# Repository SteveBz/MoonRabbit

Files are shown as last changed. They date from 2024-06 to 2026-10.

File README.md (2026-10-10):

# Moon Rabbit CO<sub>2</sub> Sensor

> **You are here:** project overview.
> Jump to: [BOM](BOM.md) · [BUILD](BUILD.md) · [SOFTWARE BUILD](SOFTWARE_BUILD.md) · [CALIBRATION](CALIBRATION.md)
> 
**A Raspberry Pi Zero 2 CO<sub>2</sub> and climate monitoring station.**

Moon Rabbit is a low-cost, open-source environmental sensor built around a Raspberry Pi Zero 2. At its core it measures **CO<sub>2</sub>** (Sensirion SCD30) and **temperature, humidity and pressure** (Bosch BME280). It can be upgraded with more precise temperature/humidity (Sensirion SHT41), air-quality gases VOC and NOx (Sensirion SGP41), sky luminosity (TSL2591), and it is compatible with a range of weather stations — notably the **Davis Vantage Pro** series, **Ambient Weather**, and **Ecowitt**.

It runs as a micro server on your WiFi, giving you 24×7 CO<sub>2</sub> and climate indicators through a browser dashboard.

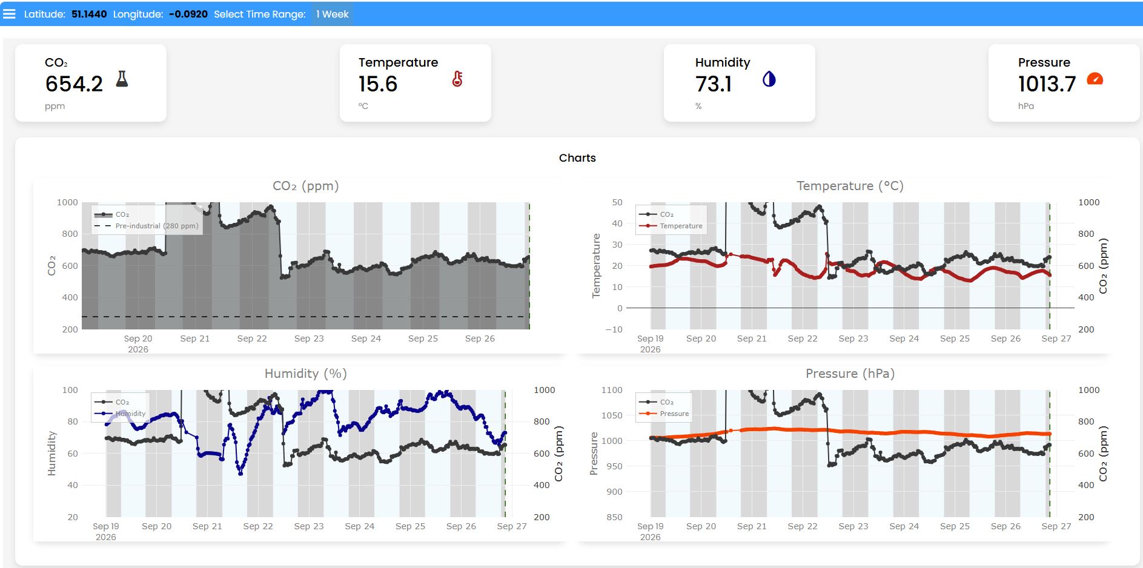
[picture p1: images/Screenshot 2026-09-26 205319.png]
Moon Rabbit sensors
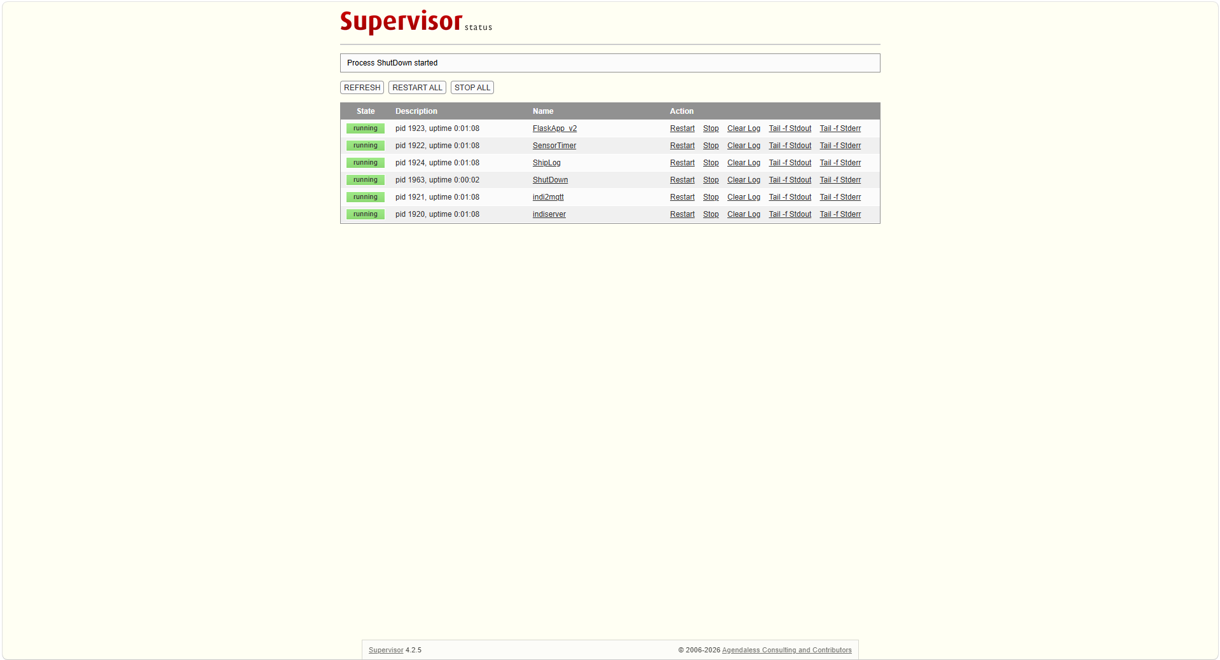
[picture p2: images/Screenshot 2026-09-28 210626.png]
Moon Rabbit control panel
|  |  |
|:---:|:---:|
| Moon Rabbit Sensors | Moon Rabbit Control Panel |

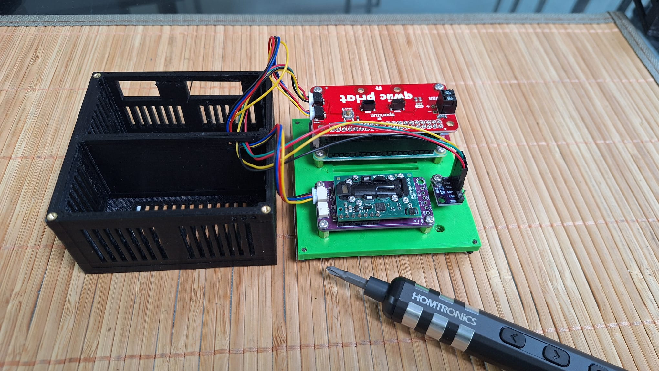
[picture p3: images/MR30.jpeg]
Moon Rabbit case
|  | |
|:---:|:---:|
| 3D-printed case with Raspberry Pi Zero 2, Qwiic pHAT, SCD30 and BME280. | |

---

## Documentation

This project is documented across four files. Start with the one that matches what you want to do.

| Document | Description |
|---|---|
| **[BOM.md](BOM.md)** | Bill of materials — every part, bolt and cable you need |
| **[BUILD.md](BUILD.md)** | Physical build — 3D printing, assembly, wiring |
| **[SOFTWARE_BUILD.md](SOFTWARE_BUILD.md)** | Software installation — OS, Python, Supervisor, MQTT, weather-station bridges |
| **[CALIBRATION.md](CALIBRATION.md)** | Sensor calibration and validation (in progress) |

### Typical build sequence

1. Order the parts listed in **[BOM.md](BOM.md)**.
2. Print the case and assemble the hardware per **[BUILD.md](BUILD.md)**.
3. Flash and configure the Pi per **[SOFTWARE_BUILD.md](SOFTWARE_BUILD.md)**.
4. (Optional) Calibrate the CO<sub>2</sub> sensor per **[CALIBRATION.md](CALIBRATION.md)**.

---

## Hardware design files

The 3D-printed case is provided as two STL files in the repository root:

- [`MoonRabbitCase_v0.4.stl`](MoonRabbitCase_v0.4.stl) — the base
- [`CarbonSensorStand_v0.9.stl`](CarbonSensorStand_v0.9.stl) — the shell / stand

Print settings and assembly guidance are in **[BUILD.md](BUILD.md)**.

---

## Licence

Software: [MIT](LICENSE) — see the `LICENSE` file.
Hardware design files: [CC BY-SA 4.0](https://creativecommons.org/licenses/by-sa/4.0/).

## Acknowledgements

- Bosch, Sensirion, SparkFun and Adafruit for sensors and open-source libraries
- The [`indi2mqtt`](https://github.com/rkaczorek/indi2mqtt) project for the Vantage Pro bridge
- [`ecowitt2mqtt`](https://github.com/bachya/ecowitt2mqtt) for the Ecowitt / Ambient Weather bridge

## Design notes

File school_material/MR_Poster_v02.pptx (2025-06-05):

## Climate change and Moon Rabbit

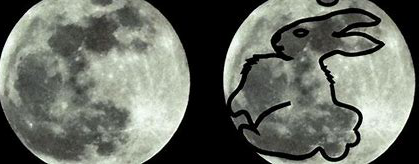
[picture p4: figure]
Image result for moon rabbit

## Moon Rabbit Projects

- Building Moon Rabbit: Construct and deploy a DIY, Moon Rabbit CO₂ monitors to empower students to collect and analyse environmental data
- CO₂ and Learning: Measure classroom CO₂ levels and correlate them with student concentration and test performance over a term.
- Traffic and Air Quality: Compare CO₂ levels in classrooms at varying distances from major roads to assess the impact of traffic emissions.
- CO₂ and the Daily Cycle: Track diurnal CO₂ changes in school grounds to explore links between photosynthesis, cloud cover and air quality.
- Many more...

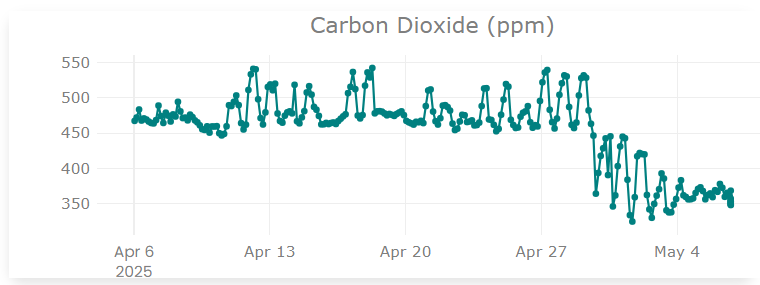
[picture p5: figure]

Skills developed
These projects help students build real-world scientific and technical skills, including 3D printing, coding and electronics (Raspberry Pi), sensor calibration, environmental data collection, data analysis, graphing and critical thinking. They also encourage teamwork, project planning, experimental design, and communication — all while connecting science learning to urgent global challenges like climate change.

## Climate change & Moon Rabbit

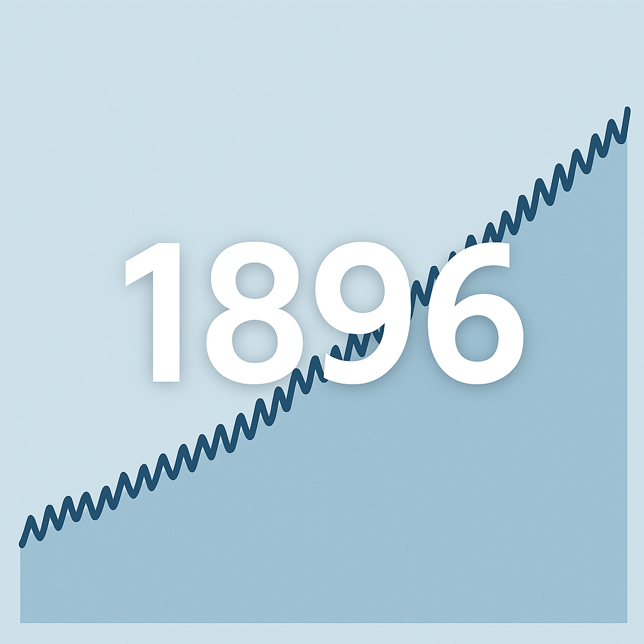
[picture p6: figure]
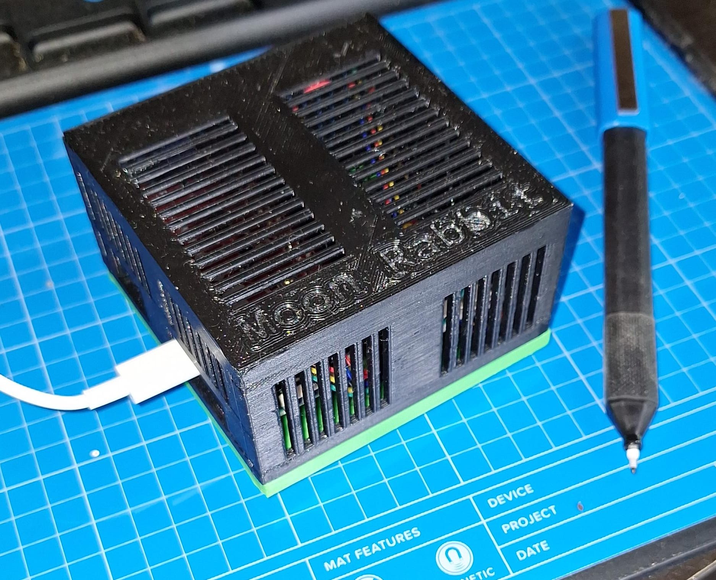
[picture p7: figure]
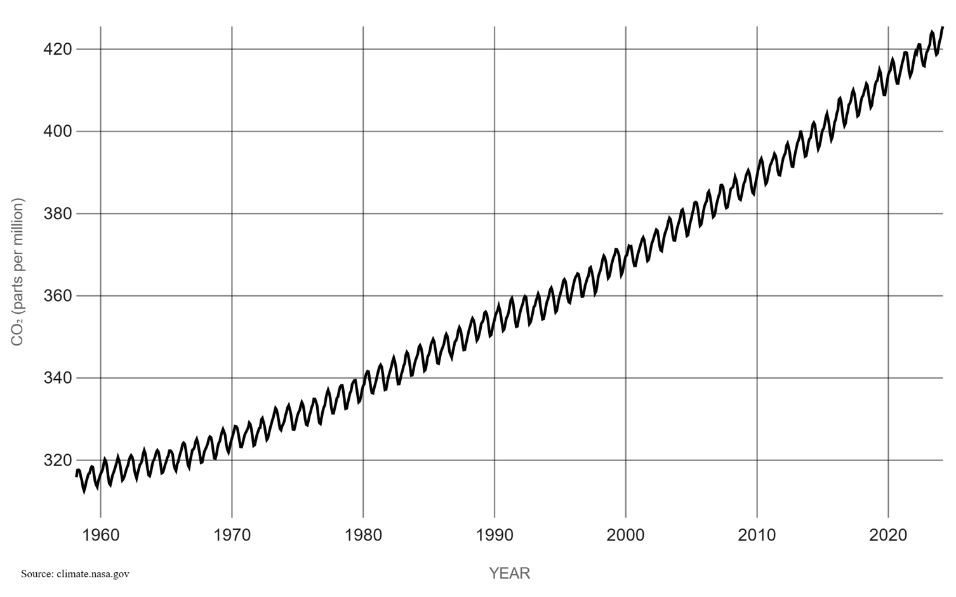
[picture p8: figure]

Kyoto
Protocol

Paris
Accord

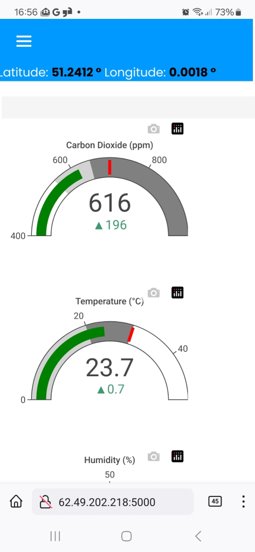
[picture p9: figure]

Build your own CO2 sensor to educate and empower
Self-directed learning for the education & STEM community
Enables students, educators & families to build and deploy their own devices
Together, we are building a global CO2 community to inform, inspire, and help shape a more sustainable future.
Real-time CO2 data on your mobile or PC
Explore globally via an interactive map
Promotes environmental awareness and STEM education

Atmospheric
CO2

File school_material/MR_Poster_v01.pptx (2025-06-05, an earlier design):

## Climate change and Moon Rabbit

Image result for moon rabbit

## Climate change & Moon Rabbit


Kyoto
Protocol

Paris
Accord


Self-built, dynamic real-time CO2 sensor designed to educate and empower communities worldwide.
Captures CO2 readings continuously, publishing data to your mobile device or PC and globally via an interactive map to explore in detail.
Moon Rabbit is a programme of self-build, experimentation and self-directed learning, tailored for the education community.
By enabling students, educators and families to build and deploy their own Moon Rabbit devices, the project fosters environmental awareness and hands-on STEM education.
Together, we are building a community-driven, global CO2 map to inform, inspire, and help shape a more sustainable future.

Atmospheric
CO2

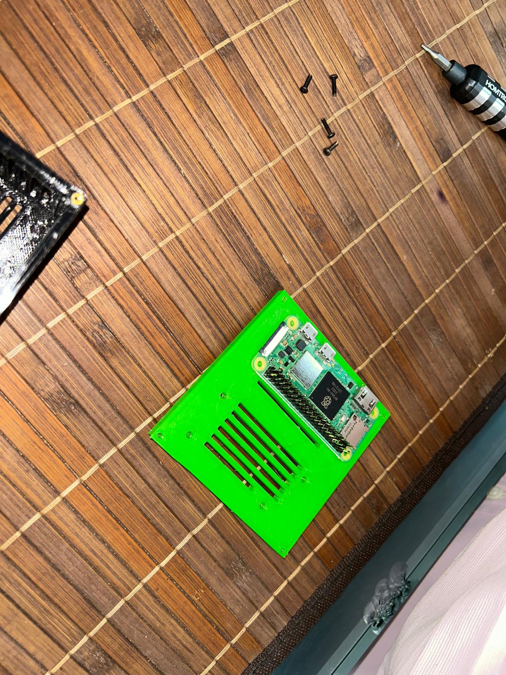
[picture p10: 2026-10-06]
images/MR17.jpeg

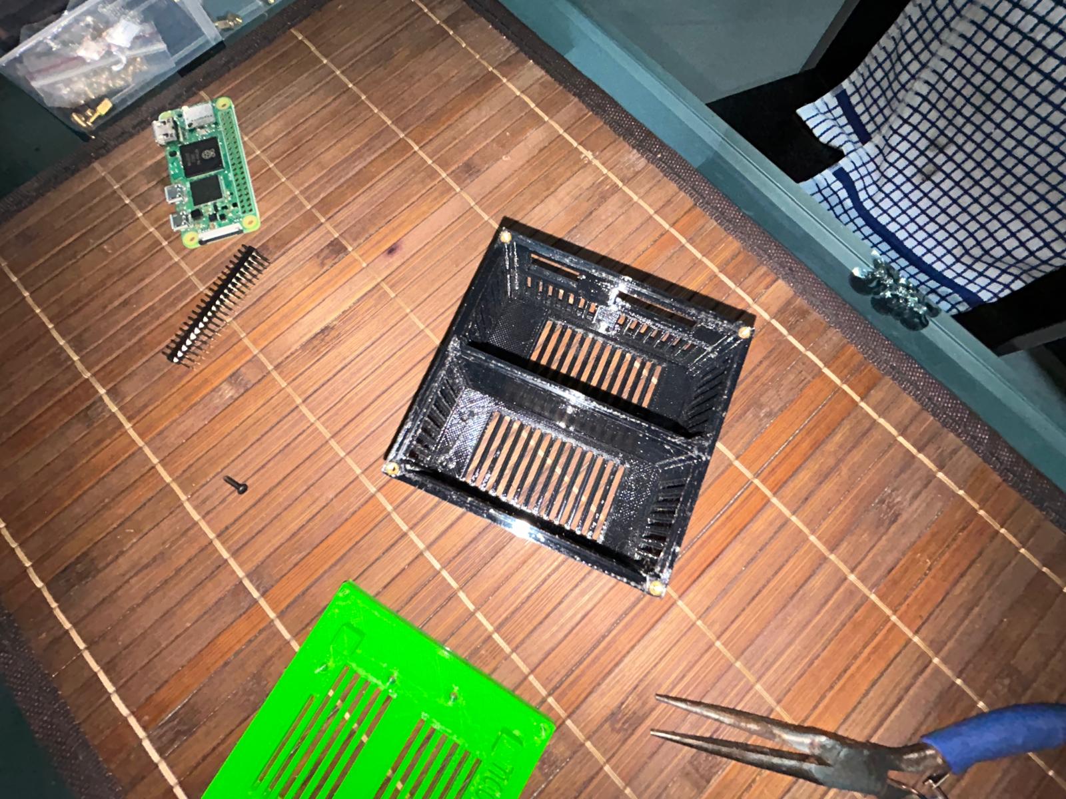
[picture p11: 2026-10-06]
images/MR9.jpeg

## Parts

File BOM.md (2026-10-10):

# Bill of Materials

> **You are here:** bill of materials — the parts list.
> Jump to: [README](README.md) · [BUILD](BUILD.md) · [SOFTWARE BUILD](SOFTWARE_BUILD.md) · [CALIBRATION](CALIBRATION.md)

Everything required to build one Moon Rabbit station. Prices are indicative (GBP, 2026), exclude shipping, and assume a UK/EU supplier. Substitute your preferred source.

## Enclosure

| Item | Qty | Notes | Source |
|---|-----|---|---|
| 3D-printed base | 1 | [`MoonRabbitCase_v0.4.stl`](MoonRabbitCase_v0.4.stl) | Print locally |
| 3D-printed shell | 1 | [`CarbonSensorStand_v0.9.stl`](CarbonSensorStand_v0.9.stl) | Print locally |
| M2 threaded inserts (shell) | 4 | Heat-set, ~4 mm | Generic |
| M3 threaded inserts (base) | 8 | Heat-set | Generic |
| M2 × 8 mm hex-head bolts | 4 | Attach shell to base | Generic |
| M2.5 × 6 mm cross-head bolts | 8 | Mount Pi and Qwiic HAT | Generic |
| M2.5 × 6 mm standoffs | 8 | Between Pi and Qwiic HAT | Generic |
| M2.5 × 11 mm standoffs | 2 | Sensor mounting | Generic |

## Electronics

| Item | Qty | Notes | Source |
|---|-----|---|---|
| Raspberry Pi Zero 2 W **or** WH | 1 | **WH** = pre-soldered GPIO header (recommended) | Pi Hut / Adafruit |
| 40-pin GPIO header | 1 | Only if using the non-WH board | Generic |
| SparkFun Qwiic pHAT for Pi | 1 | I²C breakout + Qwiic socket | SparkFun |
| Bosch BME280 breakout | 1 | Qwiic or pinout version | Adafruit / SparkFun |
| Sensirion SCD30 CO<sub>2</sub> sensor | 1 | NDIR. Qwiic version recommended | Sensirion / SparkFun |
| Qwiic-to-Qwiic cable, 10 cm | 1 | HAT → SCD30 | SparkFun |
| Qwiic-to-4-pin-female cable | 1 | HAT → BME280 (pinout version only) | SparkFun |
| MicroSD card, 32 GB, Class 10 | 1 | Samsung / SanDisk recommended | Generic |
| MicroSD card reader | 1 | For flashing the Pi | Generic |

## Optional upgrades

| Item | Qty | Notes | Source |
|---|-----|---|---|
| SHT41 breakout | 1 | Better humidity precision than BME280 | Adafruit / SparkFun |
| SGP41 breakout | 1 | VOC / NOx gas sensing | Sensirion / Adafruit |
| TSL2591 breakout | 1 | Sky luminosity (lux, IR, full spectrum) | Adafruit |
| Qwiic cable, 5 cm | 2–3 | One per upgrade sensor | SparkFun |
| IP65 enclosure, clear window | 1 | For the outdoor TSL2591 | Generic |
| Outdoor mounting bracket | 1 | For the IP65 enclosure | Generic |
| 4-core cable, ~2 m | 1 | TSL2591 (outdoor) → main case | Generic |
| 4-pole 2.5 mm panel socket | 1 | On the main case | Generic |
| 4-pole 2.5 mm plug | 1 | On the outdoor box | Generic |

## Tools

| Item | Notes |
|---|---|
| Electric screwdriver | e.g. Homtronics 37 in 1 electric screwdriver — speeds assembly |
| Miniware TS101 soldering iron | Heat-set inserts, pin headers |
| Solder, 0.6–0.8 mm lead-free | Fine-pitch work |
| Soldering stand / helping hands | Holds small boards during soldering |
| Silicone soldering mat | Heat-resistant, keeps parts in place |

## Not included

- **Power supply** — the Pi Zero 2 W needs a **5 V, 2.5 A micro-USB** supply (not USB-C).
- **Weather station** — Vantage Pro, Ambient Weather, or Ecowitt, purchased separately. See [SOFTWARE_BUILD.md](SOFTWARE_BUILD.md) for setup.

## Approximate cost

| Tier | Cost (GBP) |
|---|---|
| Core kit | £70–£90 |
| + SHT41 | +£12 |
| + SGP41 | +£20 |
| + TSL2591 outdoor kit | +£25 |
| + Weather station | £150–£500 (model dependent) |

---

*See [BUILD.md](BUILD.md) for assembly, [SOFTWARE_BUILD.md](SOFTWARE_BUILD.md) for the software setup.*

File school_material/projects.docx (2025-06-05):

# CO2 Monitoring Projects for After-School Club

# Summary

This document provides a comprehensive collection of CO2 monitoring projects designed for an after-school club using cheap pre-built 3D sensors that measure CO2, temperature, pressure, and humidity. The projects span various environments and learning objectives, offering engaging hands-on activities for students to understand environmental monitoring and the carbon cycle.

# Project Development Process

1. Brainstorming: We researched and developed 16 diverse project ideas spanning environmental monitoring and experimental approaches
2. Selection: We selected 8 projects based on engagement potential, educational value, and feasibility for after-school implementation
3. Detailed Development: Each selected project was developed with comprehensive procedures, materials lists, and expected outcomes
4. Validation: All projects were validated for relevance, feasibility, and educational value in an after-school setting

# Recommended Projects

Here is a list of project outlines:

### 1. Living Near a Road

- Measure and compare CO₂ levels at different distances from a busy road.
- Investigate the relationship between traffic density and CO₂ concentration.
- Assess potential health or environmental impacts on residents.

### 2. Urban vs. Rural Living (CO₂)

- Compare CO₂ levels in urban and rural school locations.
- Analyse how population density and transport patterns affect air quality.
- Discuss implications for sustainable living and urban planning.

### 3. Gas Central Heating (CO₂)

- Measure indoor CO₂ during heating vs. non-heating periods.
- Compare homes with gas heating to those using alternatives (e.g., electric).
- Examine the role of ventilation and insulation in indoor air quality.

### 4. Living Near an Industrial Area (CO₂)

- Monitor CO₂ near industrial zones vs. residential zones.
- Investigate possible spikes during working hours or specific processes.
- Explore links between industrial activity, emissions, and local environment.

### 5. Year-on-Year Change (CO₂)

- Compare CO₂ data from the same period across multiple years.
- Identify trends and possible causes (e.g., policy changes, weather patterns).
- Use historical data to project future scenarios or improvements.

### 6. Daily Variation and Photosynthesis

- Record CO₂ levels over 24-hour cycles in areas with and without vegetation.
- Identify patterns linked to photosynthesis during daylight hours.
- Discuss the importance of green spaces in regulating CO₂.

### 7. Student Performance or Behaviour vs. CO₂

- Track classroom CO₂ levels and correlate with concentration or test results.
- Observe behavioural patterns at high vs. low CO₂ levels.
- Propose ventilation or scheduling strategies to improve learning conditions.

### 8. Collaborating with Other Schools

- Share CO₂ data with schools in different locations or countries.
- Compare environmental impacts of geography, infrastructure, and lifestyle.
- Develop joint reports or campaigns on improving air quality.

### 9. Classroom Air Quality Investigation

- Monitor CO₂ levels in different classrooms to understand ventilation and occupancy effects.
- 2–4 week time-frame with minimal additional resources required.
- Strong connections to environmental science and building health.

### 10. CO₂ in Crowded vs. Empty Spaces

- Investigate how human occupancy affects CO₂ build-up in enclosed spaces.
- Shorter 1–2 week time-frame ideal for maintaining engagement.
- Immediate relevance to student experience with clear, observable results.

### 11. Plant Photosynthesis and CO₂ Study

- Create controlled environments to measure how plants affect CO₂ levels.
- 2–3 week time-frame with moderate resource needs (plants, containers).
- Excellent hands-on learning about photosynthesis and the carbon cycle.

### 12. Home vs. School Environmental Comparison

- Compare CO₂ and environmental factors between homes and school buildings.
- 2–4 week time-frame requiring permission for home sensor use.
- Strong personal relevance increases student engagement.

### 13. School Microclimate Mapping

- Create maps of CO₂, temperature, pressure, and humidity across the school campus.
- 3–5 week time-frame with excellent environmental diversity.
- Develops spatial mapping and data visualization skills.

### 14. Composting and Decomposition CO₂ Study

- Monitor CO₂ production during decomposition of organic materials.
- 3–5 week time-frame with moderate resource needs.
- Strong connections to biology, carbon cycle, and sustainability.

### 15. Weather and CO₂ Relationship Study

- Investigate correlations between weather conditions and CO₂ levels.
- Consider shortening from proposed 4–6 weeks to fit club schedule.
- Excellent connections to meteorology and climate science.

### 16. Traffic and Air Quality Correlation

- Measure how vehicle traffic affects local CO₂ levels at varying distances.
- Requires careful safety protocols for roadside measurements.
- Strong real-world relevance to environmental science and transportation.

# Implementation Recommendations

1. Getting Started: Begin with projects to build student confidence and skills
2. Project Selection: Choose subsequent projects based on student interest and available resources
3. Adaptability: Modify project scope as needed to fit your specific club schedule and equipment
4. Documentation: Encourage students to maintain detailed records of their observations and measurements
5. Extension: Consider culminating with a school environmental fair to showcase student findings.

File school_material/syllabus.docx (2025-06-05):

# Moon Rabbit Syllabus

First Term

### Term 1 Introduction: Building Moon Rabbit

Term 1 of the after-school STEM course provides students with the foundational knowledge and technical skills required to build a Moon Rabbit CO2 sensor which we will deploy in Terms 2 and 3 (see CO2 Monitoring Projects document).

The Moon Rabbit is a compact, Raspberry Pi–based CO2 monitoring system designed to collect CO2 measurements and associated metrics. During this first term, students will construct and deploy of their own Moon Rabbit units while developing skills in 3D design, electronics assembly, programming and calibration.

#### Focus of Term 1

Term 1 is structured around guided skill-building, preparation, build and calibration of the Moon Rabbit sensor. Students will:

- Gain an overview of the Moon Rabbit project and its objectives
- Learn the basics of 3D modelling using TinkerCAD
- Design/Modify and print custom enclosures for their devices
- Develop practical soldering skills and assemble core electronic components
- Install and configure the Raspberry Pi operating system
- Begin programming in Python, including basic control structures and system navigation
- Calibrate and test their Moon Rabbits

Students will work in pairs throughout the term, encouraging collaboration and peer learning. Team roles will be established early to support division of tasks during the project.

#### Outcomes

By the end of Term 1, students are expected to have:

- Completed and printed their custom Moon Rabbit enclosures
- Installed key components, including Raspberry Pi Zero and sensors
- Installed Raspberry Pi OS and configured the system for operation
- Installed and tested pre-built Python scripts for system control and data handling
- Calibrated and tested the Moon Rabbits

This work ensures that students are well-prepared to move into the applied phases of the course in Terms 2 and 3, where the emphasis shifts to CO2 monitoring in different circumstances and determining the impact of varying levels of CO2 on their environments.

### Week 1: Introduction and Project Overview

Objectives:

- Introduce students to the project goals and timeline
- Familiarise students with Moon Rabbit basics
- Form working pairs and establish team roles.
- Learn basics of 3D design
- Start designing an enclosure

Activities:

1. Welcome and introduction to the project (10 minutes)
2. Overview of Moon Rabbit and its capabilities (30 minutes)
3. Demonstration of a completed Moon Rabbit (20 minutes)
4. Form pairs (10 minutes)
5. Team building activity: Pairs create team names and discuss project goals (15 minutes)
6. Introduction to 3D design principles (20 minutes)
7. Overview of TinkerCAD 3D design software (15 minutes)

Homework: Design a hollow project box on TinkerCAD.

### Week 2: 3D Design Introduction

Objectives:

- Understand design considerations for electronics enclosures
- Complete Moon Rabbit designs.

Activities:

1. Feedback on Project Box designs (15 minutes)
2. Review of design principles and addressing questions (15 minutes)
3. Measuring Moon Rabbit for SD Slot (15 minutes)
4. Pairs begin designing their own SD Slots (30 minutes)
5. Finalising Moon Rabbit designs with proper ventilation and access ports (20 minutes)
6. Peer review of designs in groups (15 minutes)
7. Saving designs and preparing for next session (10 minutes)

Homework: Finalise Moon Rabbit designs.

### Week 3: Finalising 3D Design and Starting Prints

Objectives:

- Prepare files for 3D printing.
- Introduction to Cura slicing software.
- Slice Moon Rabbit case.
- Start printing process.
- Learn soldering safety and techniques
- Practice basic soldering skills

Activities:

1. Introduction to Cura slicing software and print settings (20 minutes)
2. Preparing files for printing and estimating print times (20 minutes)
3. Starting the printing process for some groups (20 minutes)
4. Introduction to soldering safety and equipment (20 minutes)
5. Demonstration of proper soldering techniques (20 minutes)
6. Solder BME280 joints (20 minutes)

Homework: Complete printing.

### Week 4: Soldering RPi 0 headers

Objectives:

- Prepare Raspberry Pi headers for the project.
- Clean up prints

Activities:

1. Inspecting solder joints and troubleshooting common issues (15 minutes)
2. Practice soldering with simple components (header pins to Raspberry Pi Board) (60 minutes)
3. Inspecting solder joints and troubleshooting common issues (15 minutes)
4. Clean-up and proper disposal of soldering materials (5 minutes)
5. Collecting completed 3D prints (10 minutes)
6. Post-processing of 3D Moon Rabbit cases (sanding, spray) (20 minutes)

Homework: Complete clean-up.

### Week 5: Assembly and Integration

Objectives:

- Assemble 3D printed enclosures
- Mount Raspberry Pi and sensors
- Test the integrated system

Activities:

1. Mounting Raspberry Pi in the enclosure (30 minutes)
2. Installing sensors in appropriate locations (30 minutes)
3. Connecting all components in the final configuration (30 minutes)
4. Initial testing of the assembled system (30 minutes)

Homework: Prepare for final testing and think about potential projects.

### Week 6: Operating System Setup and Basic Linux Commands

Objectives:

- Install and configure Raspberry Pi OS
- Learn basic Linux commands
- Understand file system navigation

Activities:

1. Review of first half and address questions (15 minutes)
2. Install Raspberry Pi OS using the Raspberry Pi Imager (30 minutes)
3. First boot and initial configuration (20 minutes)
4. Basic setup: Connecting Pi to monitor, keyboard, mouse, connect to WiFi (40 minutes)
5. Introduction to Terminal and basic Linux commands (cd, ls, mkdir, etc.) (10 minutes)
6. Saving work and proper shutdown procedures (5 minutes)

Homework: Practice Linux commands using an online terminal simulator

### Week 7: Introduction to Python Programming

Objectives:

- Learn Python basics
- Write simple programs on the Raspberry Pi
- Understand variables, loops, and conditionals

Activities:

1. Introduction to Python and why it's used for this project (15 minutes)
2. Setting up Python development environment on Pi (15 minutes)
3. Guided coding: Variables, data types, and simple operations (30 minutes)
4. Pair programming exercise: Creating a simple temperature monitoring program (30 minutes)
5. Introduction to conditional statements and loops (20 minutes)
6. Saving and running Python scripts (10 minutes)
7. Introduction to sensor calibration principles (20 minutes)

Homework: Complete a simple Python challenge related to weather data

### Week 8: Testing, and Troubleshooting

Objectives:

- Ensure all systems are functioning correctly
- Troubleshoot any issues

Activities:

1. Final system checks and troubleshooting (30 minutes)
2. Testing the complete CO2 monitoring system (20 minutes)
3. Each pair presents their project and demonstrates functionality (30 minutes)

Homework:

### Week 9: Calibration with Vacuum Pump and Calibration Gas

Objectives:

- Understand the importance of sensor calibration
- Learn calibration techniques for pressure and CO2 sensors
- Implement calibration in code

Activities:

1. Safety briefing for working with vacuum pumps and calibration gas (15 minutes)
2. Demonstration of calibration setup and equipment (20 minutes)
3. Calibrating pressure sensors using vacuum pump (30 minutes)
4. Calibrating CO2 sensors using calibration gas (30 minutes)
5. Implementing calibration offsets in Python code (5 minutes)

Homework:

### Week 10: Catchup, Final Testing and Presentation

Objectives:

- Complete any unfinished work from previous weeks
- Ensure all systems are functioning correctly
- Discuss future applications
- Present final projects

Activities:

1. Catchup time for groups who need to complete previous steps (30 minutes)
2. Final calibration checks and adjustments (20 minutes)
3. Each pair presents their project and demonstrates functionality (30 minutes)
4. Discussion of potential applications and future enhancements (15 minutes)
5. Project wrap-up and celebration of achievements (5 minutes)

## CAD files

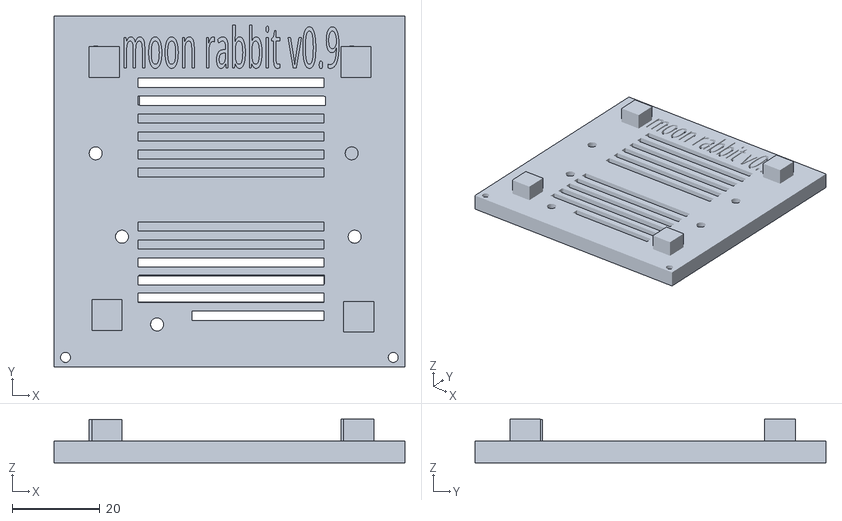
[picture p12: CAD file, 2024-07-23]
CarbonSensorStand_v0.9.stl
80.0 x 80.0 x 10.0

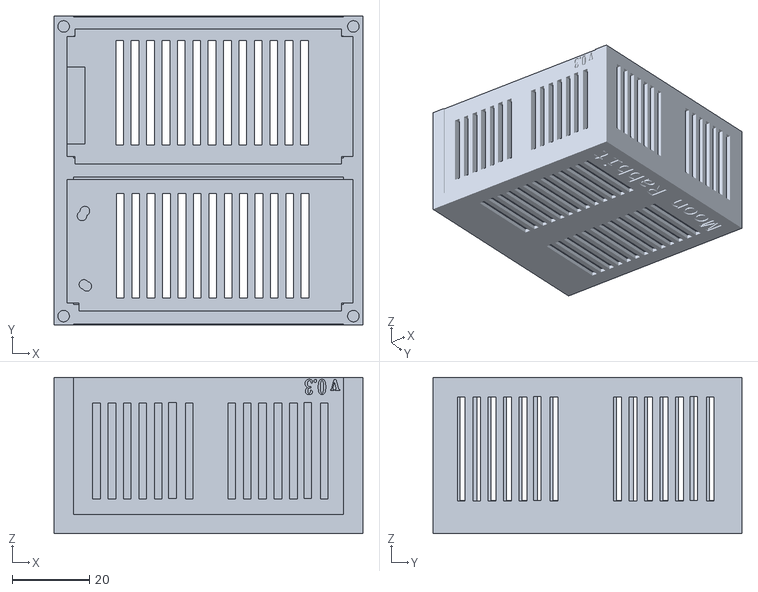
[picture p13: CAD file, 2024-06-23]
MoonRabbitCase_v0.4.stl
80.0 x 80.0 x 40.5

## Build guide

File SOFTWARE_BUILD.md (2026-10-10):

# Software Build #

Installation and configuration of the Moon Rabbit software stack on the Raspberry Pi Zero 2.

> **You are here:** software build — OS, Python, Supervisor, MQTT.
> Jump to: [README](README.md) · [BOM](BOM.md) · [BUILD](BUILD.md) · [CALIBRATION](CALIBRATION.md)

Once you have built the Moon Rabbit

You install the software as follows.

If starting with blank micro SD card:
## Flash the Micro SD card with the Rapberry Pi Imager 
#Use settings: "Raspberry Pi Zero 2 W", "64 Bit", <inserted drive>

# MoonRabbit setup

## Via a keyboard, mouse and screen through the rpi0 OTG port
Connect your keyboard and mouse to the OTG port via a OTG (On-The-Go) USB hub with a micro USB plug. Connect the monitor to the mini-HDMI port and boot by plugging the power cable in.  

On first start, setup the default user name "pi" and password "RaspberryPi"

Connect to WiFi

Enable Raspberry Pi Connect if you like.

"Skip" OS Update

Restart

### Set up WiFi or Network
If WiFi not yet connected:
Connect to the WiFi using the icon at the top right of the screen.

### Set up SSH & I2C

Menu>Preferences>Praspberry Pi Configuration>Interface>SSH

Menu>Preferences>Praspberry Pi Configuration>Interface>I2C

Menu>Preferences>Praspberry Pi Configuration>Interface>VNC

Menu>Preferences>Raspberry Pi Configuration>Localisation>Locale
Menu>Preferences>Raspberry Pi Configuration>Localisation>Timezone
Menu>Preferences>Raspberry Pi Configuration>Localisation>Keyboard if necessary
Menu>Preferences>Raspberry Pi Configuration>Localisation>WiFi Country

## Via SSH

You'll need the IP address of your raspberry pi. Get it from
```
(venv) pi@raspberrypi:~ $ ifconfig | grep 192
        inet 192.168.1.61  netmask 255.255.255.0  broadcast 192.168.1.255
```
And it's the address of the format 192.168, but not ending 255, so in this case its 192.168.1.61

### Fix swap memory default
The initial default, virtual memory allocation is very small.  You need to expand it to allow many things, such as updating software.

Run swapon command
```
swapon
> NAME      TYPE  SIZE   USED PRIO
> var/swap file 100M 100M   -2
```
Swap Memory is 100 MB
```
sudo nano /etc/rpi/swap.conf
```
Check swap size, 1024 MB
```
[Zram]
#RamMultiplier=1
#MaxSizeMiB=2048
#FixedSizeMiB=
# Writeback settings (for zram+file mechanism):
#WritebackTrigger=auto
#WritebackInitialDelay=180min
#WritebackPeriodicInterval=24h
zram-size = 1024M

```
Use Control-s to save the changes and control-x to exit nano.
Then reboot Moon Rabbit, to apply the changes.
```
sudo reboot
```
Check swapsize again
```
swapon --show
> NAME      TYPE  SIZE   USED PRIO
> var/swap file 1024M 377.8M   -2
```
Swap size has changed

### Supervisord

Supervisord allows remore control of the software on the Raspberry Pi Zero 2 W from a browser on the same WiFi LAN.

Install Supervisord
```
# Temporary apt bug workaround
# sudo apt install vlc-bin=1:3.0.21-0+rpt4+deb12u1 vlc-plugin-skins2=1:3.0.21-0+rpt4+deb12u1 vlc-plugin-qt=1:3.0.21-0+rpt4+deb12u1
# Update and upgrade the system packages
sudo apt-get update && sudo apt-get upgrade -y
# Install necessary packages
sudo apt-get install -y supervisor
```

# Edit Supervisor configuration to allow web interface
sudo nano /etc/supervisor/supervisord.conf
Add the following lines to enable the web interface
```
[inet_http_server]
port=*:9001
```
Use Control-s to save the changes and control-x to exit nano.
### Enable hardware interfaces in the Raspberry Pi configuration
IIC or I2C (I-squared-C, or I-two-C), is the interface that links all the sensors to the Raspberry Pi Zero 2 W

sudo nano /boot/firmware/config.txt

```
# Uncomment  or add these lines to enable the hardware interfaces

dtparam=i2c_arm=on
#dtparam=i2s=on
dtparam=spi=on

# Set I2C Clock Speed
dtparam=i2c_arm_baudrate=10000
```
Use Control-s to save the changes and control-x to exit nano.
### Install Moon Rabbit Software
```
# Clone the project repository
git clone https://github.com/SteveBz/MoonRabbit
cd MoonRabbit/
# Set up Python virtual environment and activate it
python3 -m venv venv
. venv/bin/activate
sh install3.sh
sh install-sw.sh
sh install.sh
```

### If you want a hotspot do the following (optional)

Optionally set up an Access Point called "MoonRabbit" with password "raspberry".  It's good practice to name them uniquely if you are collaborating with others. 

```
nmcli connection add type wifi ifname wlan0 con-name MoonRabbit autoconnect no ssid MoonRabbit
nmcli connection modify MoonRabbit 802-11-wireless.mode ap 802-11-wireless.band bg ipv4.method shared
nmcli connection modify MoonRabbit wifi-sec.key-mgmt wpa-psk
nmcli connection modify MoonRabbit wifi-sec.psk "raspberry"
nmcli connection modify MoonRabbit connection.autoconnect yes
```

### Test Moon Rabbit in a browser
Navigate to a browser, open two tabs and type in the following IP adresesses:
```
<your ip address>:5000
<your ip address>:9001
```
Eg, like this, substituting your address for the example.
```
192.168.1.61:5000
192.168.1.61:9001
```

---

*See [CALIBRATION.md](CALIBRATION.md) for sensor calibration procedures.*

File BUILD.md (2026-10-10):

# Moon Rabbit CO2 Sensor Build Instructions

> **You are here:** physical build — printing, assembly, wiring.
> Jump to: [README](README.md) · [BOM](BOM.md) · [SOFTWARE BUILD](SOFTWARE_BUILD.md) · [CALIBRATION](CALIBRATION.md)

Here are the strep-by-step build instructions.

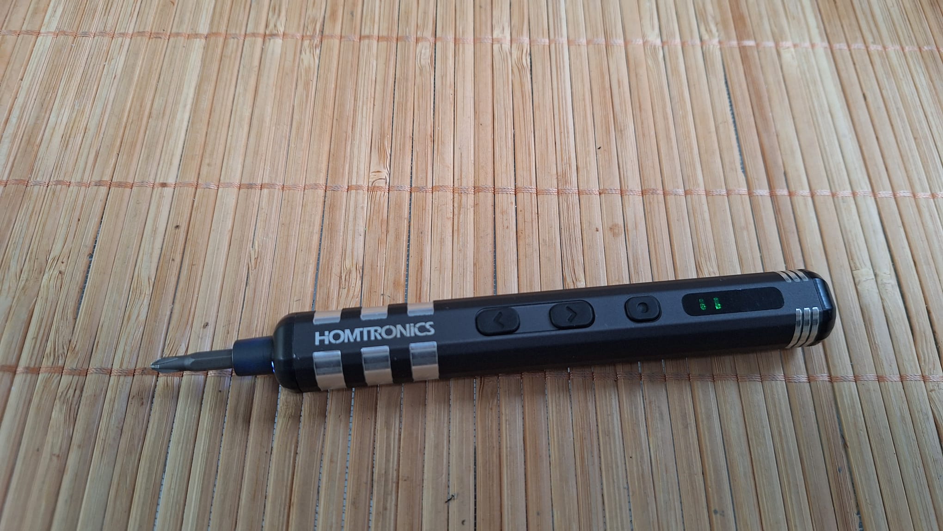
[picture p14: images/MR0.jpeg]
MR0
|  | |
| :---: | :---: |
| I use the HOMTRONICS electric screwdriver.  It's much easier. | |
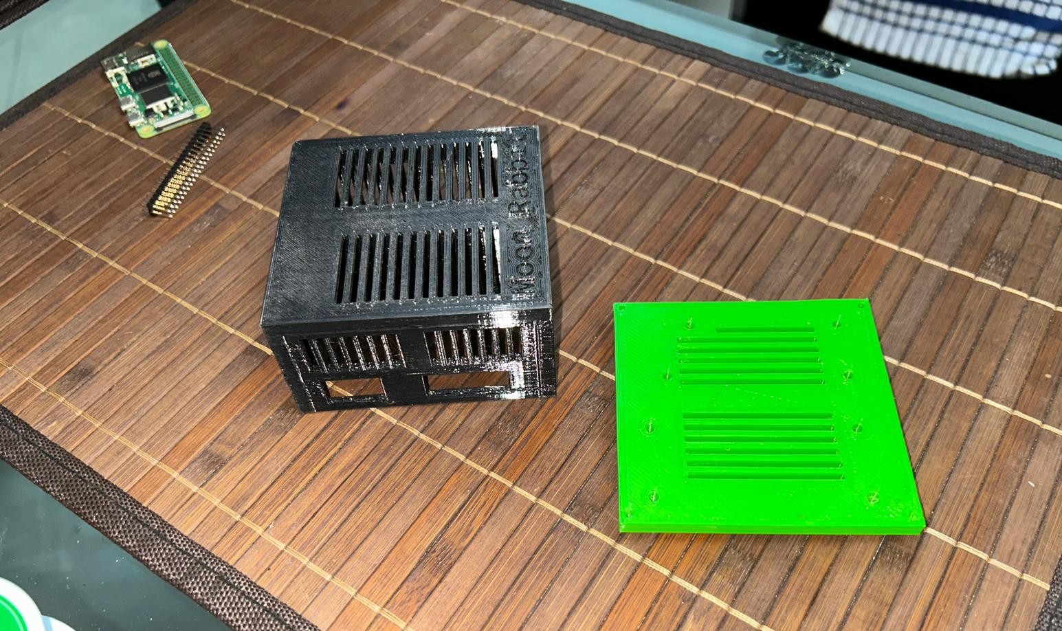
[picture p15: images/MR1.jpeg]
MR1
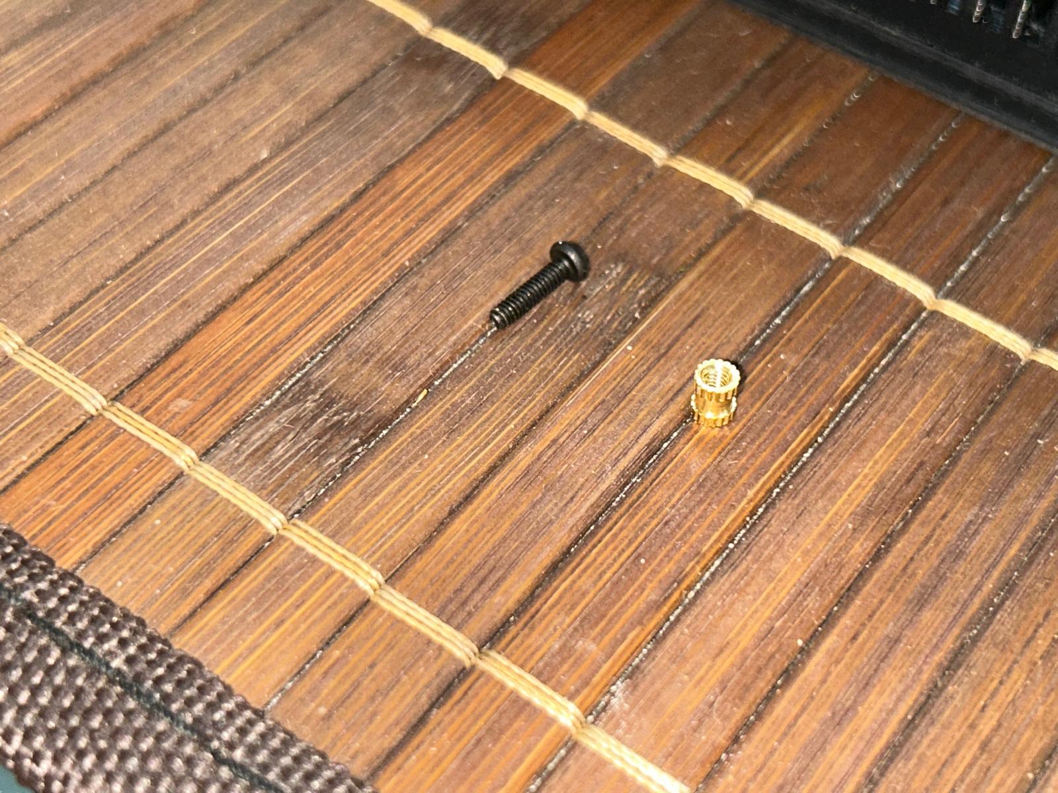
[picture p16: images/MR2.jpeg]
MR2
|  |  |
| Take the 3D printed Moon Rabbit case and stand | And four inserts and bolts |
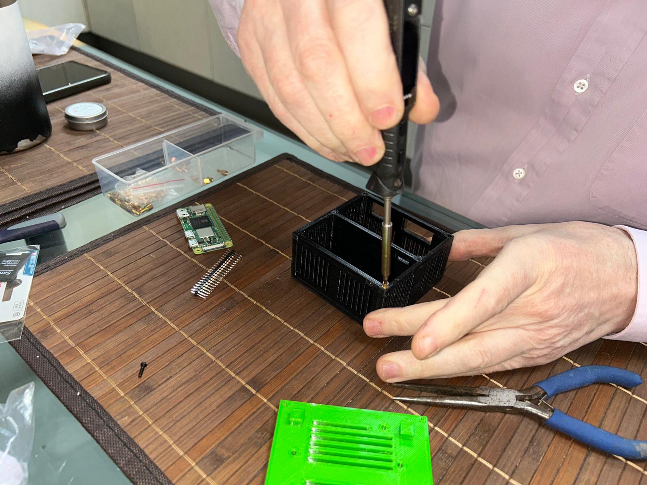
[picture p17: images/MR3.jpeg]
MR3
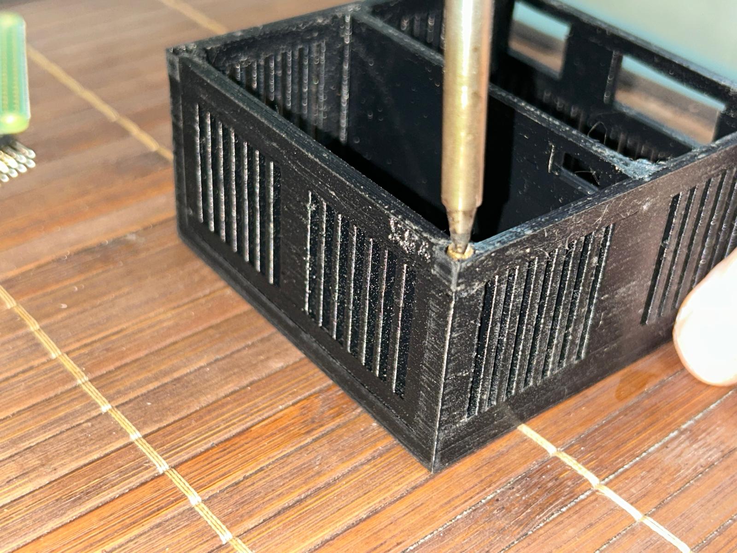
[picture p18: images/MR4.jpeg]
MR4
|  | |
| Use soldering iron to place insert into hole (part 1) | Place insert into hole (part 2) |
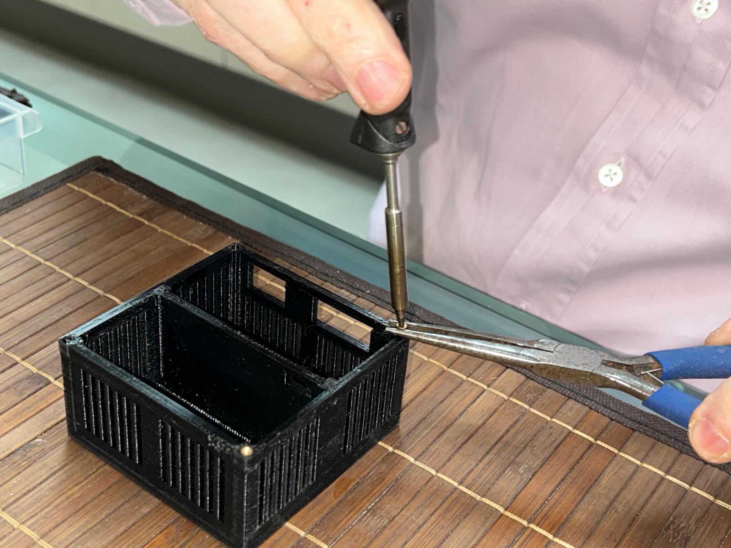
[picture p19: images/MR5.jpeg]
MR5
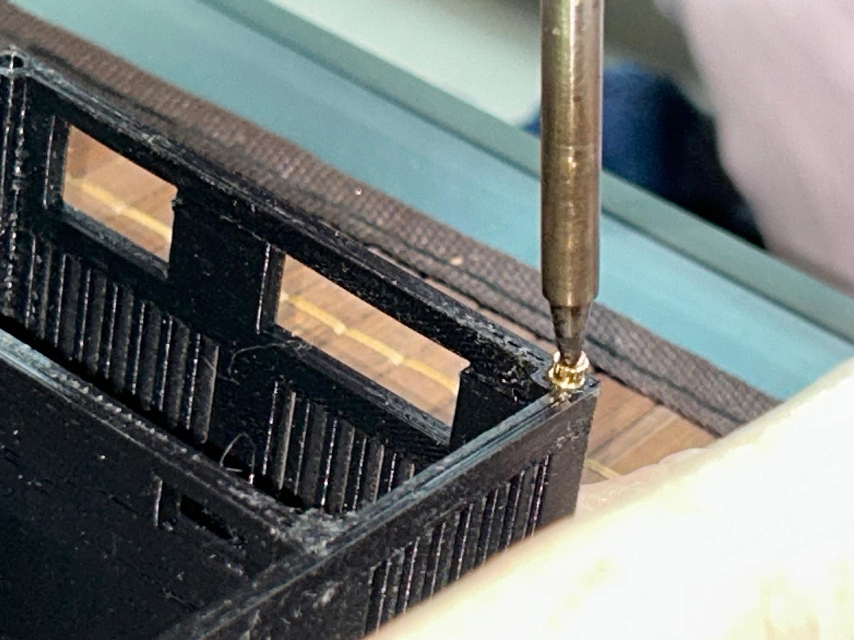
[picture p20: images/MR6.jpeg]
MR6
|  | |
| Place insert into hole (part 3) | Place insert into hole (part 4) |
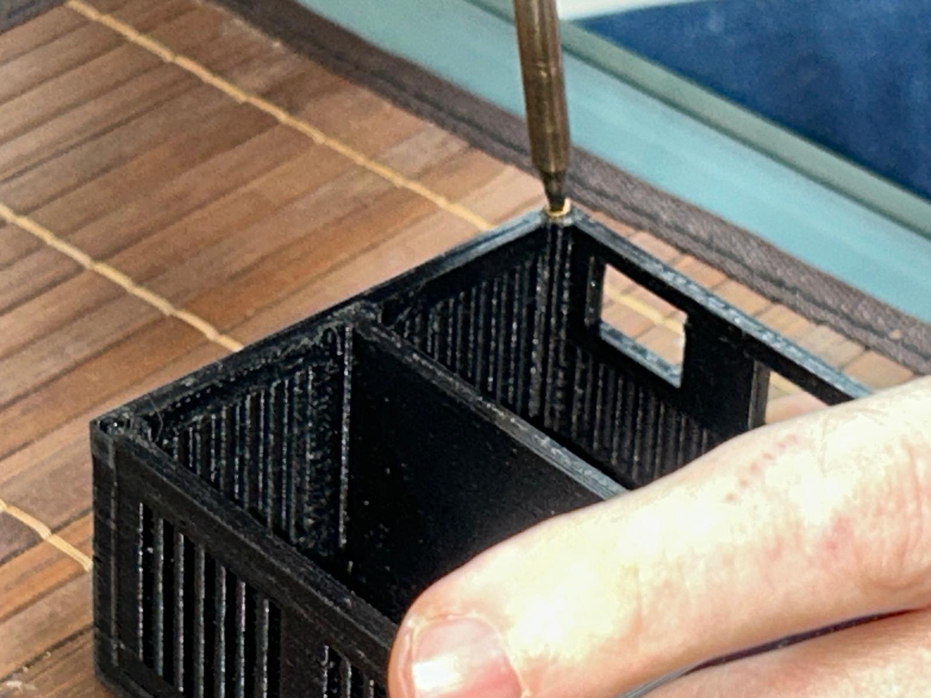
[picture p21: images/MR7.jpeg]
MR7
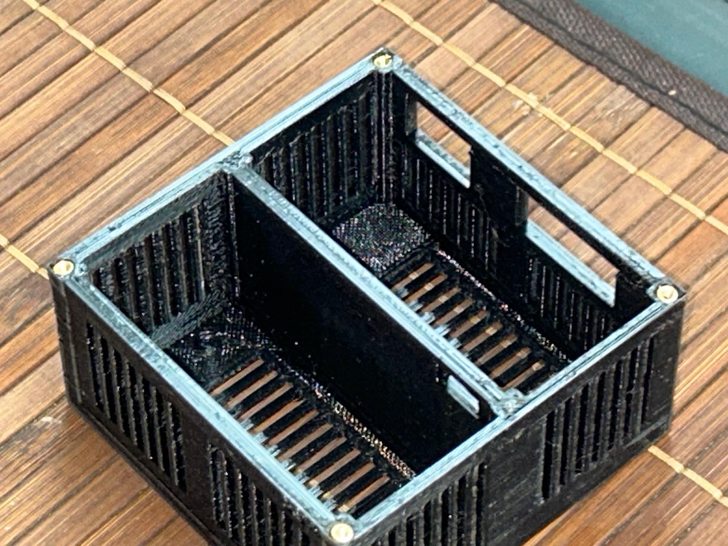
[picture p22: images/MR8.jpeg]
MR8
|  |  |
| Place insert into hole (part 5) | Finished article with four inserts |
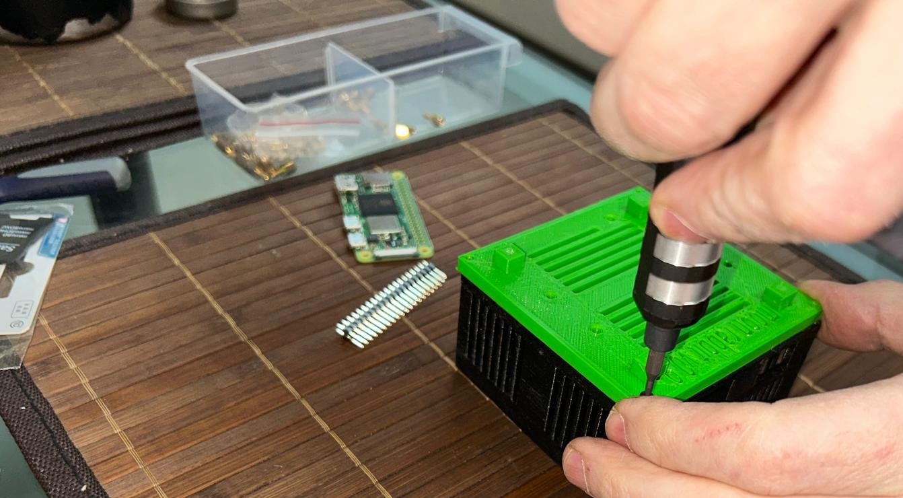
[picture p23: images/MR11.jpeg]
MR11
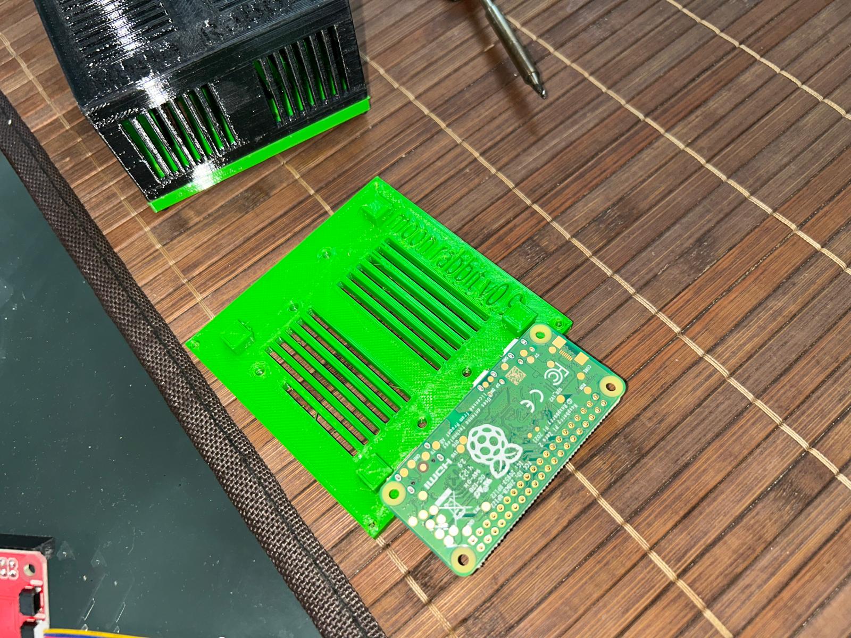
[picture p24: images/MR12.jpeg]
MR12
|  |  |
| Test mount base and cover to maker sure that the holes line up.  | The Raspberry Pi Zero 2 W comes in two forms with and without GPIO headers. If you've bought it without headers (cheaper) then you need to solder the headers yourself). |
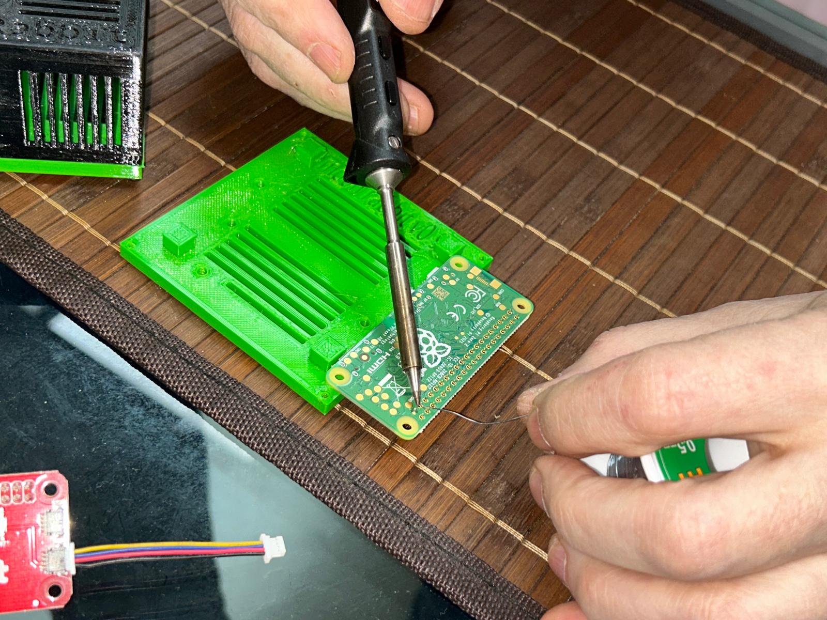
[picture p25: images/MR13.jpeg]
MR13
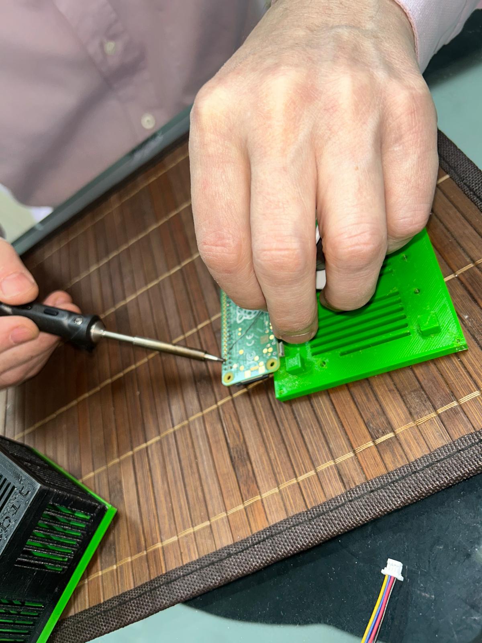
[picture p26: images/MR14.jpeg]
MR14
|  |   |
| Soldering headers (1) | Soldering headers (2) |
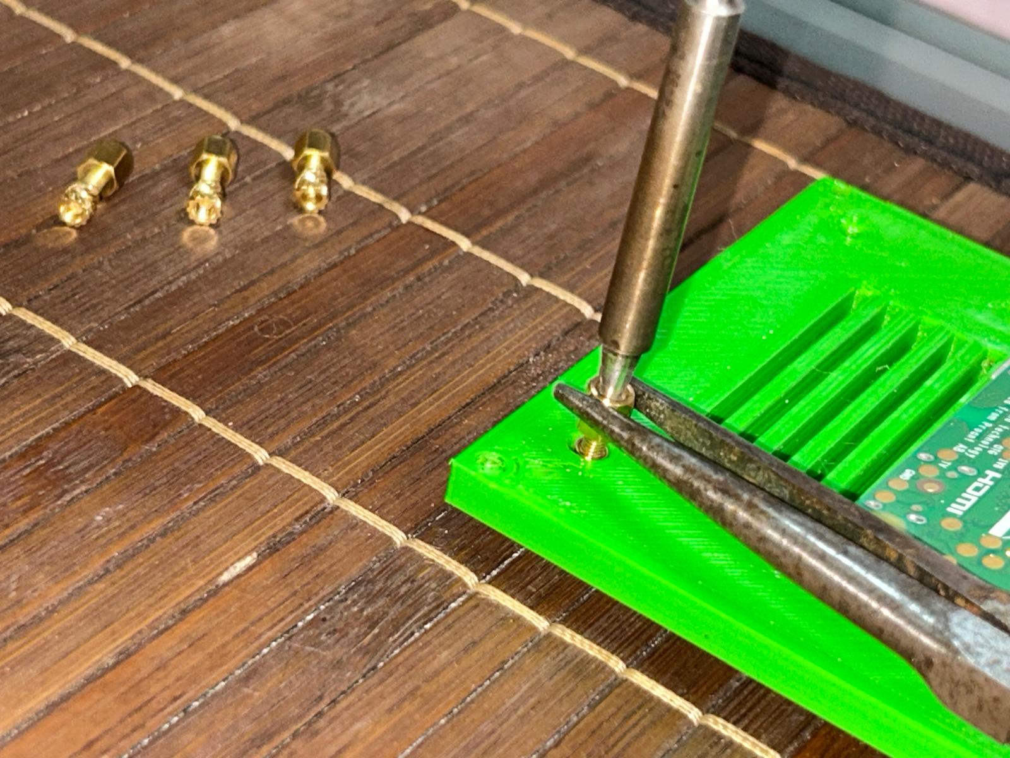
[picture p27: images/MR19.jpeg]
MR19
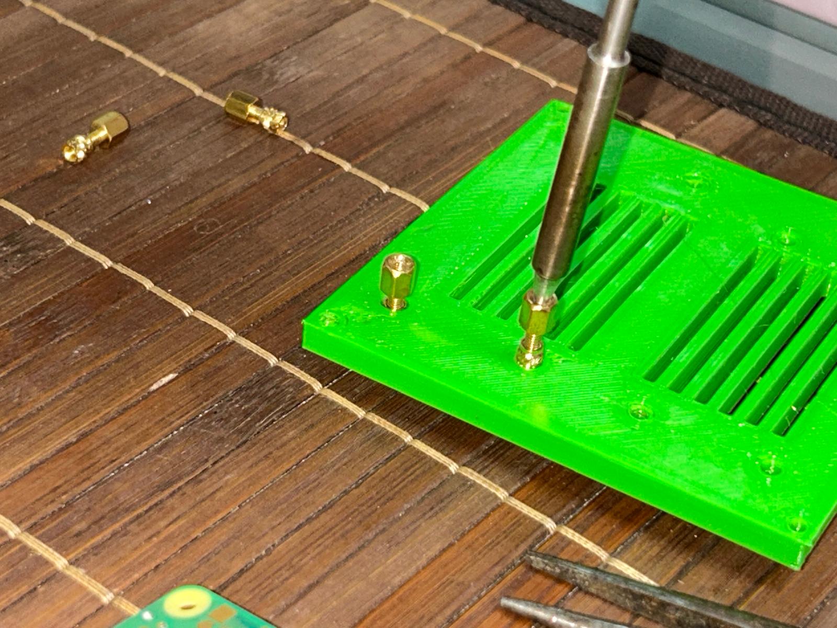
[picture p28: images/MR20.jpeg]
MR20
|  |   |
| Inserting the inserts plus 6mm standoffs with a soldering iron (1) | Inserting the inserts plus 6mm standoffs with a soldering iron (1) |
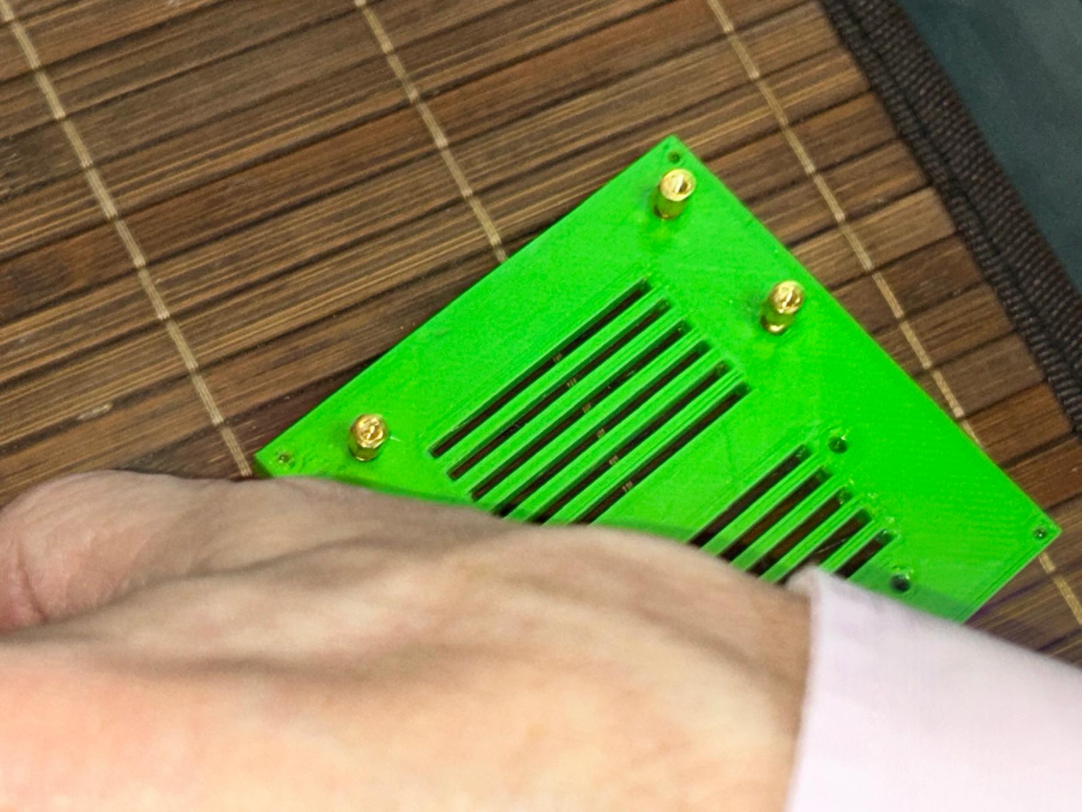
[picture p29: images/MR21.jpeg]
MR21
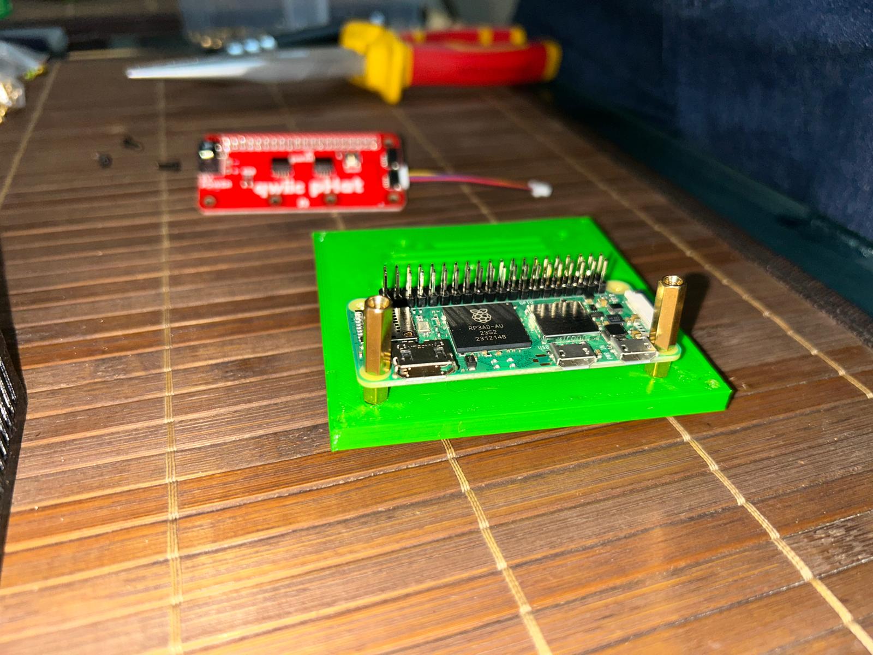
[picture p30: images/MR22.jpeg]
MR22
|  |   |
| Inserting the inserts plus 6mm standoffs with a soldering iron (3) | Pi Zero mounted on the green base plate with headers and longer standoffs for mounting Qwiic pHAT |
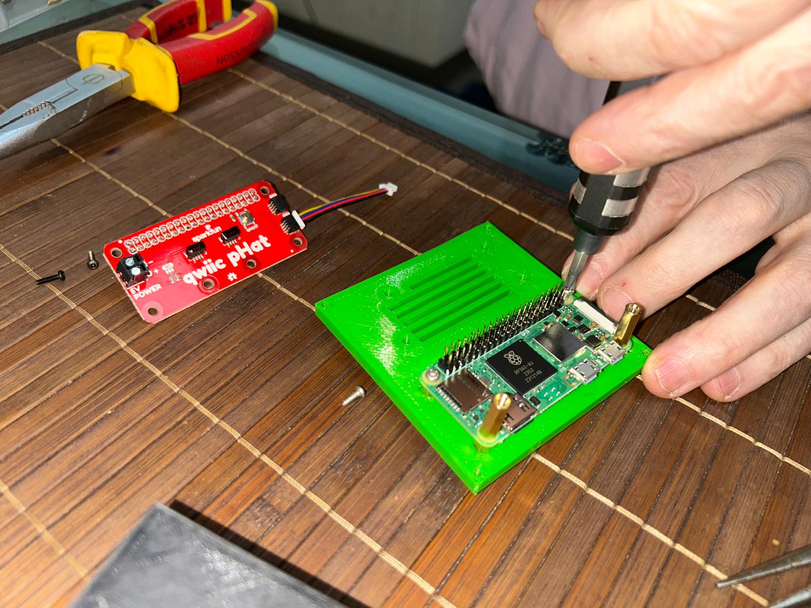
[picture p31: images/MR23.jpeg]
MR23
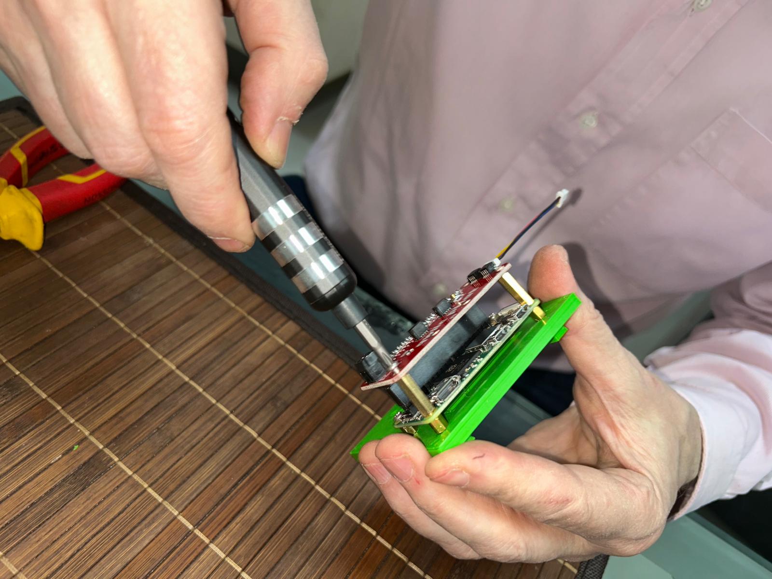
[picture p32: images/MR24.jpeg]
MR24
|  |  |
| Assembled Pi Zero and Qwiic pHAT next to the case | Connecting the Qwiic pHAT ribbon cable |
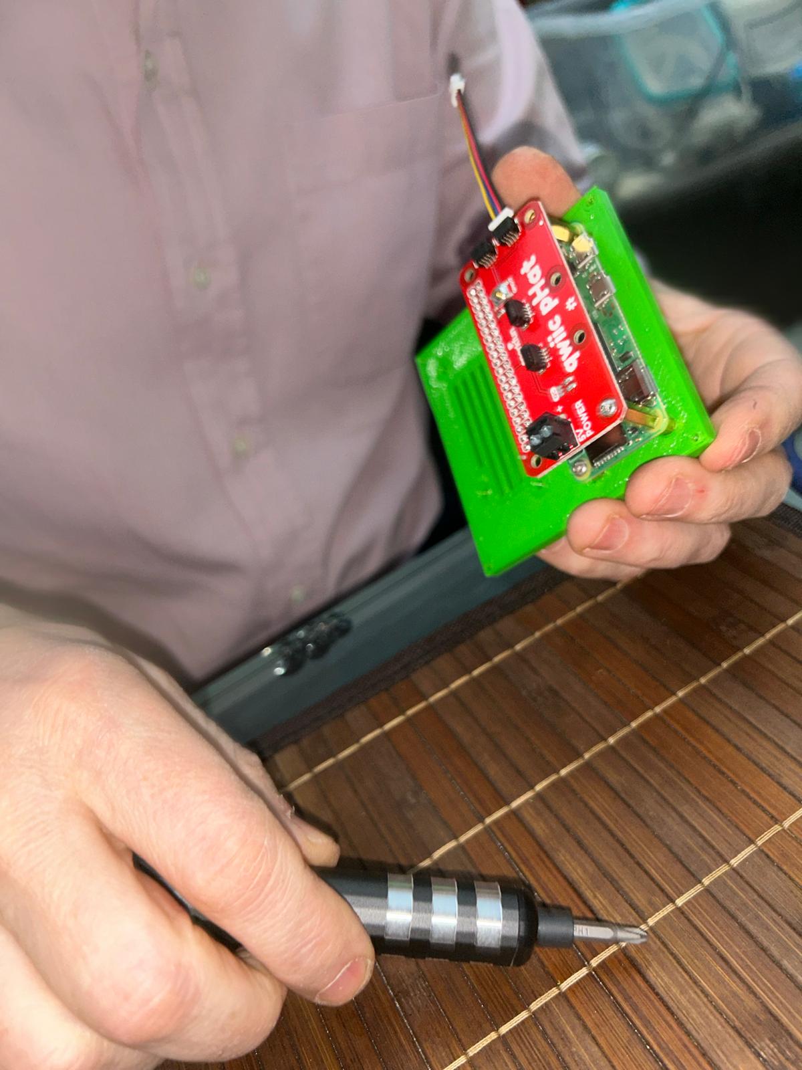
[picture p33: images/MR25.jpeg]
MR25
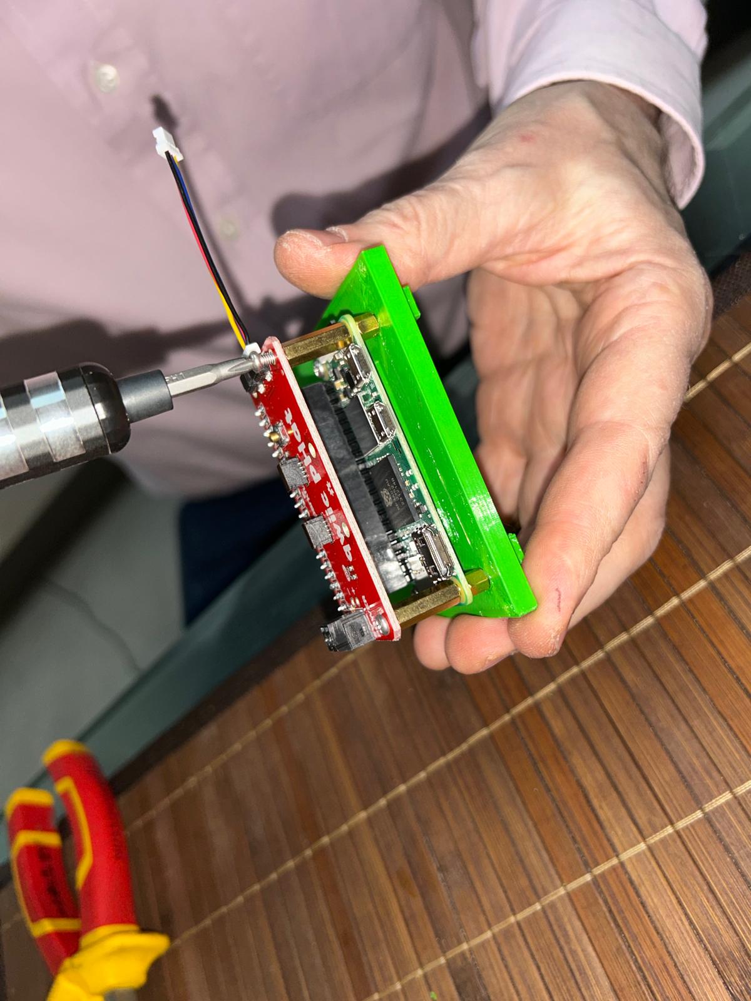
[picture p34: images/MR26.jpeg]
MR26
|  |  |
| Securing the Qwiic pHAT to the Pi Zero stack | Close-up of tightening the assembly screws |
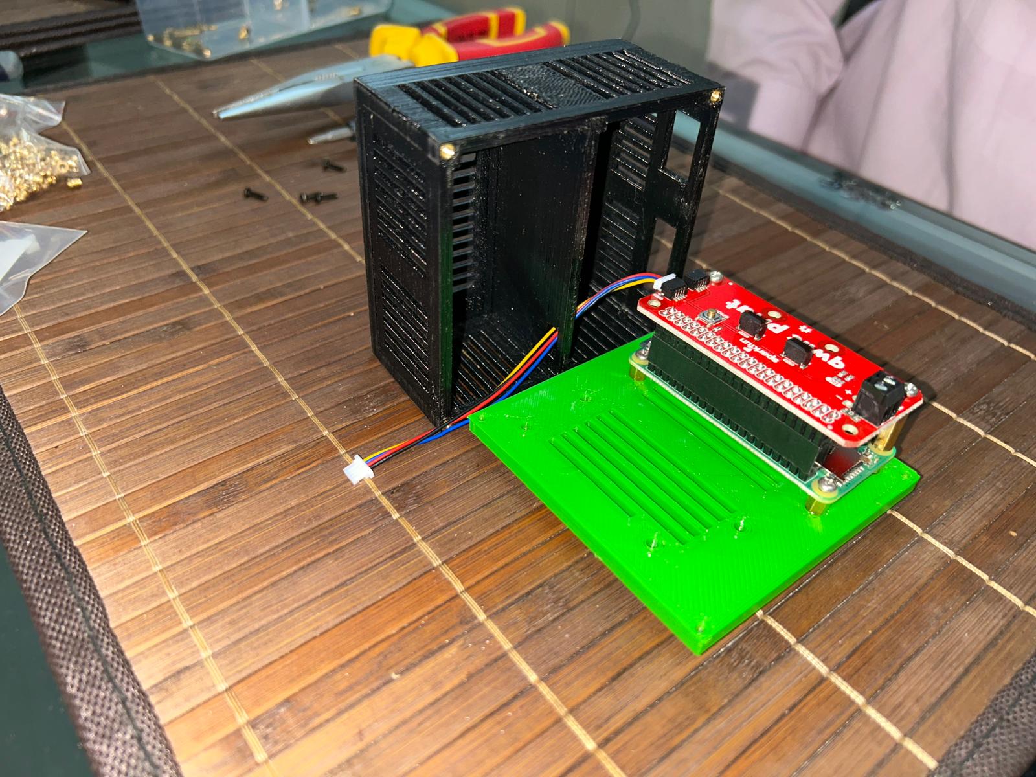
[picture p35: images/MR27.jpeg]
MR27
|  | |
| Final components laid out before final assembly | |
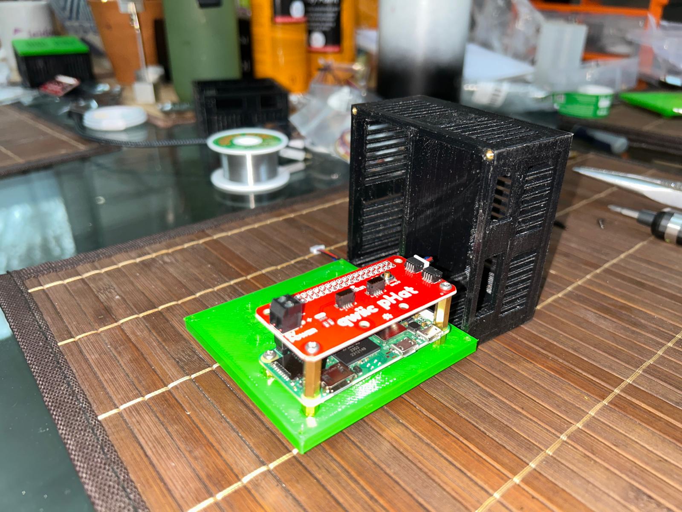
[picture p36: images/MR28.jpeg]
MR28
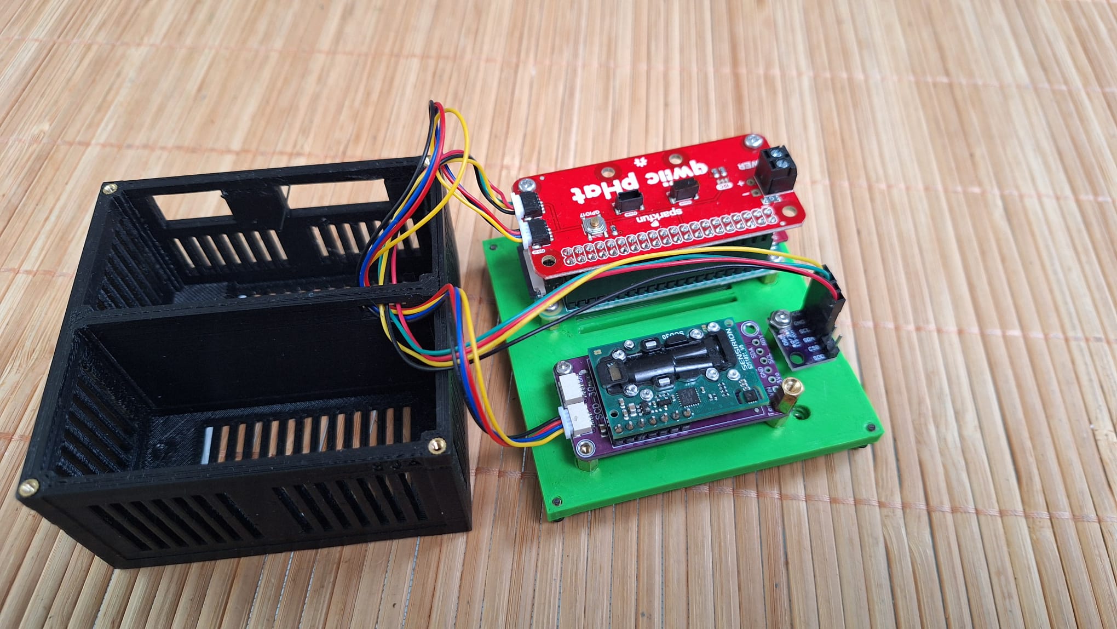
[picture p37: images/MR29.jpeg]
MR29
|  |  |
| Partial assembly of the electronics and case | Close-up of the Qwiic pHAT and sensor stack |
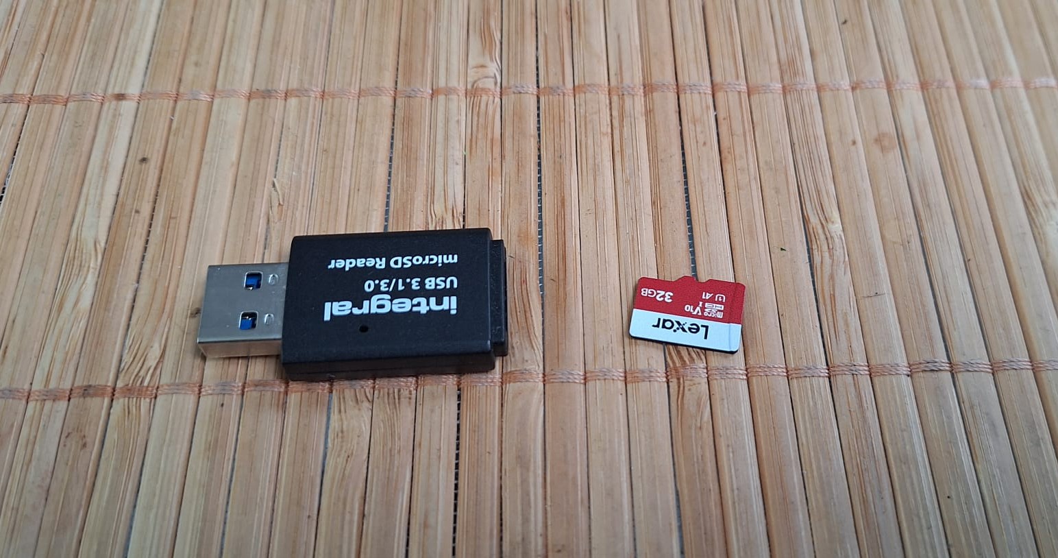
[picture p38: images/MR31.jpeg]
MR31
|  | 
| Lexar 32GB microSD card and Integral card reader | |

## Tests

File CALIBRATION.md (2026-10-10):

# Calibration

> **You are here:** calibration — validating and adjusting sensor readings.
> Jump to: [README](README.md) · [BOM](BOM.md) · [BUILD](BUILD.md) · [SOFTWARE BUILD](SOFTWARE_BUILD.md)

Procedures for validating and calibrating the Moon Rabbit sensors.

## CO<sub>2</sub> (SCD30)

The SCD30 uses NDIR (non-dispersive infrared) sensing. Out of the box, some units are accurate to within a few ppm, others can be out by 150 ppm or more.

### Reference calibration

The most reliable method is to compare against a known concentration source — for example a calibrated reference gas cylinder, or a nearby reference-grade CO<sub>2</sub> monitor.

### Field calibration

In the absence of a reference source, the following approaches help:

- **Fresh-air baseline**: place the sensor outdoors in clean air, well away from traffic and buildings, for 20–30 minutes. Fresh outdoor air is around 420 ppm. Use the SCD30's built-in `forced_recalibration` command to anchor to this value.
- **Continuous baseline correction**: the SCD30 supports automatic baseline correction (ABC), which assumes the sensor will periodically see fresh air. Enable this only if the sensor is in a space that genuinely drops to outdoor levels regularly — otherwise it will slowly drift.

### Recording the calibration

Update the following fields in `config.json`:

- `last_calibration_date` — ISO timestamp
- `last_calibration_value` — the reference ppm used

## Temperature and humidity

The BME280 and SHT41 do not normally need field calibration. If you have a reference instrument:

- SHT41 is accurate to ±0.1 °C / ±1.7 %RH
- BME280 is accurate to ±0.5 °C / ±3 %RH

If you see a systematic offset, it is more likely due to self-heating from nearby electronics than to a bad sensor. Consider re-siting.

## Pressure

Barometric pressure varies naturally by ±15 hPa over a day due to weather. Do not attempt to calibrate it in isolation — cross-check against a nearby official weather station reading after accounting for altitude difference.

## Other sensors

- **VOC / NOx (SGP41)** — needs a 10-hour burn-in and conditioning cycle before readings stabilise. No user calibration.
- **Lux (TSL2591)** — factory calibrated; no user adjustment.

---

*This document is a work in progress. Contributions welcome.*

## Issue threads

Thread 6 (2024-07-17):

calibration problem with the CO2 sensor

hrickdiz, 2024-07-17:
I have recalibrated my two Rabbits by placing both units in a CO2-free container.  Both units read Zero.  I waited more than an hour with the two of them reading Zero.  I then did the forced calibration program for each of them.  I left them in the bag for another 15 minutes.  When I removed them and waited for them to settle on new values in the room air, one reads 764 ppm and the other reads 859 ppm, both sitting on a shelf in a cabinet right next to one another.  Apparently, the "forced" calibration routine is not sufficient.

SteveBz, 2024-07-18:
I've sketched out the maths, and I think the calibration curve is mx + c it's more like a decay line, like 1 - exp [-1/x]. So x = 0 is not a useful point.

⁣Get BlueMail for Android

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

SteveBz, 2024-07-18:
I've sketched out the maths, and I think the calibration curve is mx + c it's more like a decay line, like 1 - exp [-1/x]. So x = 0 is not a useful point.

Like this:

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

hrickdiz, 2024-07-18:
How did you come up with the exponential expression?  Was this found on the manufacturer's website for the sensor?

After having done the recalibration at Zero, and after letting the two units co-exist side by side for overnight, I forced the higher unit to have the same reading as the lower unit.  After a few more hours, I will report how close they are to each other.

hrickdiz, 2024-07-18:
Attached is the "Field Calibration for the SCD30 " guidance document from Sensiron.
[Sensirion_SCD30_Field_Calibration.pdf](https://github.com/user-attachments/files/16285153/Sensirion_SCD30_Field_Calibration.pdf)

hrickdiz, 2024-07-18:
Following the guidance document, I have now placed both Rabbits outside of my window, allowed them to stabilize; one was reading about 395, the other was reading about 350.  I have recalibrated them both to read 400 ppm.

SteveBz, 2024-07-18:
That will make them equal, but not right.

⁣Get BlueMail for Android

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

hrickdiz, 2024-07-18:
the very distinction between precision and accuracy!

Right now, they are with 30 ppm of one another.

SteveBz, 2024-07-18:
It's probably more like this:

⁣Get BlueMail for Android

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

SteveBz, 2024-07-18:
This, even:

⁣Get BlueMail for Android

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

SteveBz, 2024-07-18:
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

hrickdiz, 2024-07-18:
My two units are tracking close to one another now:

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

SteveBz, 2024-07-18:
Very good. So at least it's stable.

⁣Get BlueMail for Android

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

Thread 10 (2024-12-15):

sensor failure after prolonged deployment outdoors

hrickdiz, 2024-12-15:
My MoonRabbit quit reporting values after a couple of weeks outdoors (protected from rain).  I brought it inside, but it would not boot up.  I re-flashed the SD card, reloaded the Rabbit software, and repositioned it outside.  I worked briefly and then failed again.  It is reporting the same value repeatedly.  Since it is still delivering a webpage, I assume that the Pi is working but not the sensors.  I will bring it in and replace the sensors and redeploy it.

hrickdiz, 2024-12-15:
I have unplugged the device, brought it inside, and powered it up again.  It is continuing to report the same values as it did previously when it was outside.  I will now 'update' the software and see what happens.

hrickdiz, 2024-12-15:
I have no confirmation that the software was indeed updated.  The device did not power off and reboot, but then I do not know if it was expected to do that.  I will not shut it down and power it back up manually.

hrickdiz, 2024-12-15:
The manual reboot resulted in the sensors reporting new data.  I will keep it inside for now.

SteveBz, 2024-12-15:
> It is reporting the same value repeatedly.

Good to know.  This is a locking problem.

Steve.
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

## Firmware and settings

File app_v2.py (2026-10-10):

from flask import Flask, render_template, jsonify, request
from flask_cors import CORS
from class_sensor_module import SensorModule
from class_database_mgt import DatabaseManager
from class_config_mgt import ConfigManager
import subprocess
import logging
import json
from datetime import datetime
import time

_sensor_types_cache = None
_sensor_types_cache_time = 0
_SENSOR_TYPES_TTL = 60   # seconds

# Set up logging
logging.basicConfig(level=logging.INFO)
logger = logging.getLogger(__name__)

app = Flask(__name__)
CORS(app, resources={r"/*": {"origins": "http://localhost:5000"}})
# Sensor types that are stored and aggregated but not displayed on the dashboard
HIDDEN_TYPES = {'rain_mm'}

# ==============================================================
# NEW: Sensor metadata configuration for the generic v2 API
# ==============================================================
SENSOR_METADATA = {
    "temperature": {"unit": "°C", "min": -10, "max": 50, "reference": 23, "color": "#B22222"},
    "humidity":    {"unit": "%",   "min": 20,   "max": 100, "reference": 50, "color": "#00008B"},
    "pressure":    {"unit": "hPa", "min": 850, "max": 1100, "reference": 1000, "color": "#FF4500"},
    "co2":         {"unit": "ppm", "min": 200, "max": 1000, "reference": 420, "color": "#383838"},
    "voc":         {"unit": "idx", "min": 0,   "max": 500, "reference": 100, "color": "#228B22"},
    "nox":         {"unit": "idx", "min": 0,   "max": 500, "reference": 1,   "color": "#8B0000"},
    "sky_temperature": {"unit": "°C", "min": -30, "max": 50, "reference": 0, "color": "#8A2BE2"},
    "rain_rate":   {"unit": "mm/h", "min": 0, "max": 30, "reference": 0, "color": "#1E90FF"},
    "rain_mm":     {"unit": "mm",   "min": 0, "max": 10, "reference": 0, "color": "#1E90FF"},
    "rain_today":  {"unit": "mm",   "min": 0, "max": 50, "reference": 0, "color": "#1E90FF"},
    "wind_speed":  {"unit": "m/s", "min": 0, "max": 30, "reference": 0, "color": "#32CD32"},
    "wind_direction": {"unit": "°", "min": 0, "max": 360, "reference": 0, "color": "#FFD700"},
    "rain":        {"unit": "mm", "min": 0, "max": 500, "reference": 0, "color": "#00BFFF"},
    "lux":           {"unit": "lux",  "min": 0, "max": 100000, "reference": 0, "color": "#FFD700"}
}

def get_active_sensor_types():

    global _sensor_types_cache, _sensor_types_cache_time
    now = time.time()
    if _sensor_types_cache is not None and (now - _sensor_types_cache_time) < _SENSOR_TYPES_TTL:
        return _sensor_types_cache

    db = DatabaseManager('measurement.db')
    try:
        cursor = db.conn.cursor()
        cursor.execute("SELECT DISTINCT type FROM sensor_measurement")
        rows = cursor.fetchall()
        types = [row[0] for row in rows if row[0] not in HIDDEN_TYPES]
        _sensor_types_cache = types
        _sensor_types_cache_time = now
        logger.info(f"Active sensor types found: {types}")
        return types
    except Exception as e:
        logger.error(f"Error fetching sensor types: {e}")
        return []
    finally:
        db.conn.close()

def get_sensor_metadata_for_type(sensor_type):
    default = {"unit": "", "min": 0, "max": 100, "reference": 0, "color": "#1f77b4"}
    meta = SENSOR_METADATA.get(sensor_type, default).copy()
    meta["name"] = sensor_type
    return meta

# ==============================================================
# NEW: V2 API ENDPOINTS
# ==============================================================
@app.route('/old')
def old_dashboard():
    return render_template('index_old.html')
@app.route('/v2/sensorMetadata', methods=['GET'])
def v2_sensor_metadata():
    logger.info("v2_sensorMetadata called")
    types = get_active_sensor_types()
    result = [get_sensor_metadata_for_type(t) for t in types]
    logger.info(f"v2_sensorMetadata returning {len(result)} sensor types")
    return jsonify(result)

@app.route('/v2/sensorReadings', methods=['GET'])
def v2_sensor_readings():
    logger.info("v2_sensorReadings called")
    db = DatabaseManager('measurement.db')
        
    types = get_active_sensor_types()
    readings = []
    for sensor_type in types:
        try:
            latest = db.select_measurements_by_type(sensor_type)
            if latest:
                record = latest[0]
                readings.append({
                    "name": sensor_type,
                    "value": record["value"],
                    "unit": SENSOR_METADATA.get(sensor_type, {}).get("unit", ""),
                    "min": SENSOR_METADATA.get(sensor_type, {}).get("min", 0),
                    "max": SENSOR_METADATA.get(sensor_type, {}).get("max", 100),
                    "reference": SENSOR_METADATA.get(sensor_type, {}).get("reference", 0),
                    "color": SENSOR_METADATA.get(sensor_type, {}).get("color", "#1f77b4")
                })
        except Exception as e:
            logger.error(f"Error reading {sensor_type}: {e}")
    db.conn.close()
    logger.info(f"v2_sensorReadings returning {len(readings)} readings")
    
    # Return both readings and location
    conf = ConfigManager("config.json")
    latitude  = conf.get_lat()
    longitude = conf.get_long()
    device_id = conf.get_device_id()
    return jsonify({
        "readings":  readings,
        "latitude":  latitude,
        "longitude": longitude,
        "device_id": device_id
    })

@app.route('/v2/refreshHistory', methods=['GET'])
def v2_refresh_history():
    max_points = request.args.get('maxPoints', default=360, type=int)
    duration = request.args.get('duration', default='realtime', type=str)
    logger.info(f"v2_refreshHistory called with maxPoints={max_points}, duration={duration}")
    db = DatabaseManager('measurement.db')
    types = get_active_sensor_types()
    history = {}
    for sensor_type in types:
        try:
            records = db.get_latest_measurements_by_type_and_duration(sensor_type, duration, max_points)
            data_points = []
            for rec in records:
                if isinstance(rec, dict):
                    ts = rec.get('date')
                    val = rec.get('value')
                else:
                    # fallback tuple – adjust indices if needed
                    ts = rec[2] if len(rec) > 2 else None
                    val = rec[7] if len(rec) > 7 else None
                if ts and val is not None:
                    if isinstance(ts, datetime):
                        ts = ts.isoformat()
                    data_points.append([ts, val])
            history[sensor_type] = data_points
        except Exception as e:
            logger.error(f"History error for {sensor_type}: {e}")
            history[sensor_type] = []
    db.conn.close()
    logger.info(f"v2_refreshHistory returning data for {len(history)} sensor types")
    return jsonify(history)

# ==============================================================
# LEGACY ROUTES – with added trace logging
# ==============================================================

@app.route("/")
def hello_world():
    logger.info("Legacy root (/) called – serving index.html")
    return render_template("index.html")

@app.route('/refreshHistory')
def refresh_history():
    max_points = request.args.get('maxPoints')
    duration = request.args.get('duration')
    logger.info(f"LEGACY refreshHistory called – maxPoints={max_points}, duration={duration}")
    db_manager = DatabaseManager('measurement.db')
    sensor_types = ['temperature', 'pressure', 'humidity', 'co2', 'sky_temperature', 'rain_rate', 'wind_speed', 'wind_direction', 'rain']
    historical_data = {}
    for sensor_type in sensor_types:
        try:
            historical_data[sensor_type] = db_manager.get_latest_measurements_by_type_and_duration(sensor_type, duration, max_points)
        except Exception as e:
            logger.error(f"LEGACY refreshHistory: error fetching {sensor_type}: {e}")
            historical_data[sensor_type] = []
    db_manager.conn.close()
    logger.info(f"LEGACY refreshHistory returning {len(historical_data)} sensor types")
    return jsonify(historical_data)

@app.route('/sensorReadings')
def get_sensor_data():
    logger.info("LEGACY sensorReadings called")
    db_manager = DatabaseManager('measurement.db')
    latest_entries = {}
    sensor_types = ['temperature', 'pressure', 'humidity', 'co2']
    conf = ConfigManager("config.json")
    latitude = conf.get_lat()
    longitude = conf.get_long()
    for sensor_type in sensor_types:
        try:
            [latest_entry] = db_manager.select_measurements_by_type(sensor_type)
            if latest_entry:
                latest_entries[sensor_type.lower()] = {
                    "date": latest_entry["date"],
                    "sensor": latest_entry["sensor"],
                    "latitude": latest_entry["latitude"],
                    "longitude": latest_entry["longitude"],
                    "type": latest_entry["type"],
                    "value": latest_entry["value"]
                }
        except Exception as e:
            logger.error(f"LEGACY sensorReadings: error reading {sensor_type}: {e}")
    db_manager.conn.close()
    if not latest_entries:
        logger.warning("LEGACY sensorReadings: No sensor data found")
        return jsonify({"status": "Error", "message": "No sensor data found"})
    retVal = {
        "status": "OK",
        "temperature": latest_entries["temperature"]["value"],
        "pressure": latest_entries["pressure"]["value"],
        "humidity": latest_entries["humidity"]["value"],
        "co2": latest_entries["co2"]["value"],
        "latitude": latest_entries["temperature"]["latitude"],
        "longitude": latest_entries["temperature"]["longitude"]
    }
    logger.info(f"LEGACY sensorReadings returning OK with temp={retVal['temperature']}, pressure={retVal['pressure']}, etc.")
    return jsonify(retVal)

@app.route('/update_sw', methods=['POST'])
def update_sw():
    logger.info("LEGACY update_sw called")
    print("Updating Software")
    git_pull_cmd = "git pull"
    install_cmd = "sh install.sh"
    reboot_cmd = "/usr/bin/sudo /sbin/reboot"
    try:
        subprocess.run(git_pull_cmd, shell=True, check=True)
        subprocess.run(install_cmd, shell=True, check=True)
        subprocess.run(reboot_cmd, shell=True, check=True)
    except subprocess.CalledProcessError as e:
        logger.error(f"LEGACY update_sw error: {e}")
        print(f"Error: Command '{e.cmd}' returned non-zero exit status {e.returncode}")
    return 'Software update action initiated'

@app.route('/reboot', methods=['POST'])
def reboot():
    logger.info("LEGACY reboot called")
    print("Rebooting sensor")
    command = "/usr/bin/sudo /sbin/reboot"
    subprocess.Popen(command.split(), stdout=subprocess.PIPE)
    return 'Reboot action initiated'

@app.route('/shutdown', methods=['POST'])
def shutdown():
    logger.info("LEGACY shutdown called")
    print("Shutdown sensor")
    command = "/usr/bin/sudo /sbin/shutdown now"
    subprocess.Popen(command.split(), stdout=subprocess.PIPE)
    return 'Shutdown action initiated'

@app.route('/updateLatitude', methods=['POST'])
def update_latitude():
    logger.info("LEGACY updateLatitude called")
    if request.method == 'POST':
        data = request.get_json()
        latitude = data.get('latitude')
        conf = ConfigManager()
        conf.set_lat(float(latitude))
        logger.info(f"LEGACY updateLatitude set to {latitude}")
        return jsonify({'message': 'Latitude updated successfully'}), 200
    else:
        return jsonify({'error': 'Only POST requests are allowed'}), 405

@app.route('/updateLongitude', methods=['POST'])
def update_longitude():
    logger.info("LEGACY updateLongitude called")
    if request.method == 'POST':
        data = request.get_json()
        longitude = data.get('longitude')
        conf = ConfigManager()
        conf.set_long(float(longitude))
        logger.info(f"LEGACY updateLongitude set to {longitude}")
        return jsonify({'message': 'Longitude updated successfully'}), 200
    else:
        return jsonify({'error': 'Only POST requests are allowed'}), 405

if __name__ == '__main__':
    app.run(debug=True, host='0.0.0.0')

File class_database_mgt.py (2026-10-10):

import sqlite3
from sqlite3 import Error
from datetime import datetime, timedelta
import time, math
# import pandas as pd # pip3 install pandas
import random
import logging
import json

# Set up logging
logging.basicConfig(level=logging.INFO)
logger = logging.getLogger(__name__)

from class_sqlite_diagnostic import SQLiteDiagnostic
class DatabaseManager:
    def __init__(self, db_file):
        """
        Initialize the DatabaseManager with the given database file.
        :param db_file: The path to the SQLite database file.
        """
        self.db_file = db_file
        self.conn = self.create_connection(db_file)
        self.create_table()
        self.backfill_monthly_if_empty()
        
    def create_connection(self, db_file):
        """
        Create a database connection to the SQLite database specified by db_file.
        :param db_file: The path to the SQLite database file.
        :return: The database connection object.
        """
        try:
            conn = sqlite3.connect(db_file, isolation_level=None, detect_types=sqlite3.PARSE_DECLTYPES)
            conn.row_factory = sqlite3.Row  # Enable accessing rows by column name
            conn.execute("PRAGMA journal_mode=WAL")  # Set to WAL mode for better concurrency
            conn.execute("PRAGMA wal_autocheckpoint = 500")  # -- Set a custom threshold (e.g., 500 pages, the default is 1000)
            # conn.execute("PRAGMA busy_timeout = 10000")  # Increase busy timeout to 10 seconds
            logger.info(f"Connecting SQLite version: {sqlite3.version}")
            return conn
        except Error as e:
            logger.error(f"Connection error = '{e}'")
            return None

    def create_table(self):
        """
        Create tables if they do not exist.
        """
        table_queries = [
            '''
                CREATE TABLE IF NOT EXISTS sensor_measurement (
                    device_id int,
                    id INTEGER PRIMARY KEY AUTOINCREMENT,
                    date DATETIME,
                    sensor TEXT,
                    latitude REAL,
                    longitude REAL,
                    type TEXT,
                    value REAL,
                    transferred INTEGER DEFAULT 0
                )
                
            ''',
            '''
                CREATE INDEX IF NOT EXISTS reading_index 
                    ON sensor_measurement (date, latitude, longitude, sensor, type)''',

            '''
                CREATE INDEX IF NOT EXISTS idx_raw_type
                    ON sensor_measurement (type)
            ''',
            
            '''
                CREATE INDEX IF NOT EXISTS idx_raw_type_date
                    ON sensor_measurement (type, date DESC)
            ''',
            
            '''
                CREATE TABLE IF NOT EXISTS sensor_measurement_mins (
                    id INTEGER PRIMARY KEY AUTOINCREMENT,
                    device_id INTEGER NOT NULL,
                    date TIMESTAMP NOT NULL,
                    sensor TEXT NOT NULL,
                    type TEXT NOT NULL,
                    latitude REAL NOT NULL,
                    longitude REAL NOT NULL,
                    transferred BOOLEAN NOT NULL DEFAULT 0,
                    value REAL NOT NULL,
                    max_value REAL NOT NULL,
                    min_value REAL NOT NULL,
                    UNIQUE(device_id, sensor, type, latitude, longitude, date)
                )
            ''',
            '''
                CREATE INDEX IF NOT EXISTS idx_sensor_measurement_mins 
                    ON sensor_measurement_mins (date)
            ''',
            '''
                CREATE INDEX IF NOT EXISTS idx_sensor_measurement_mins_device_sensor 
                    ON sensor_measurement_mins (device_id, sensor)
            ''',
                
            '''
                CREATE TABLE IF NOT EXISTS sensor_measurement_hours (
                    id INTEGER PRIMARY KEY AUTOINCREMENT,
                    device_id INTEGER NOT NULL,
                    date TIMESTAMP NOT NULL,
                    sensor TEXT NOT NULL,
                    type TEXT NOT NULL,
                    latitude REAL NOT NULL,
                    longitude REAL NOT NULL,
                    transferred BOOLEAN NOT NULL DEFAULT 0,
                    value REAL NOT NULL,
                    max_value REAL NOT NULL,
                    min_value REAL NOT NULL,
                    UNIQUE(device_id, sensor, type, latitude, longitude, date)
                )
            ''',
            '''
                CREATE INDEX IF NOT EXISTS idx_sensor_measurement_hours 
                    ON sensor_measurement_hours (date)
            ''',
            '''
                CREATE INDEX IF NOT EXISTS idx_sensor_measurement_hours_device_sensor 
                    ON sensor_measurement_hours (device_id, sensor)
            ''',
            '''
                CREATE TABLE IF NOT EXISTS sensor_measurement_days (
                    id INTEGER PRIMARY KEY AUTOINCREMENT,
                    device_id INTEGER NOT NULL,
                    sensor TEXT NOT NULL,
                    type TEXT NOT NULL,
                    latitude REAL NOT NULL,
                    longitude REAL NOT NULL,
                    transferred BOOLEAN NOT NULL DEFAULT 0,
                    date TIMESTAMP NOT NULL,
                    value REAL NOT NULL,
                    max_value REAL NOT NULL,
                    min_value REAL NOT NULL,
                    UNIQUE(device_id, sensor, type, latitude, longitude, date)
                )
            ''',
            '''
                CREATE INDEX IF NOT EXISTS idx_sensor_measurement_days 
                    ON sensor_measurement_days (date)
            ''',
            '''
                CREATE INDEX IF NOT EXISTS idx_sensor_measurement_days_device_sensor 
                    ON sensor_measurement_days (device_id, sensor)
            ''',
            '''
                CREATE TABLE IF NOT EXISTS sensor_measurement_months (
                    id INTEGER PRIMARY KEY AUTOINCREMENT,
                    device_id INTEGER NOT NULL,
                    sensor TEXT NOT NULL,
                    type TEXT NOT NULL,
                    latitude REAL NOT NULL,
                    longitude REAL NOT NULL,
                    transferred BOOLEAN NOT NULL DEFAULT 0,
                    date TIMESTAMP NOT NULL,
                    value REAL NOT NULL,
                    max_value REAL NOT NULL,
                    min_value REAL NOT NULL,
                    UNIQUE(device_id, sensor, type, latitude, longitude, date)
                )
            ''',
            '''
                CREATE INDEX IF NOT EXISTS idx_sensor_measurement_months 
                    ON sensor_measurement_months (date)
            ''',
            '''
                CREATE INDEX IF NOT EXISTS idx_sensor_measurement_months_device_sensor
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

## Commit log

2024-08-11 Fix lat/long to 4 dp
    [class_config_mgt.py]
2024-08-11 Fix IP address on app.py
    [app.py]
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2024-09-17 Error checking for PyINdi
    [class_sensor_module.py]
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2026-08-30 Remove redundant client event processing
    Removed unnecessary call to processEvents() in the sensor module.
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2026-08-30 Add checks for wind attributes in sensor module
    Added checks for wind_direction, wind_speed, and rain_rate attributes before inserting measurements into the database.
2026-08-30 Refactor weather data insertion and cleanup
    Removed print statements for wind direction, wind speed, and rain rate. Added a loop to insert all weather data keys except 'device_name'.
2026-08-30 Copy device readings to weather_data for processing
    Copy device_readings to weather_data for insertion.
2026-08-31 Improve weather data insertion in sensor module for vantage.
    Refactor weather data insertion logic to skip device name, ignore specific keys, and avoid duplicates.
    [class_sensor_module.py]
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2026-09-04 Implement v2 API with sensor metadata and readings
    Added v2 API endpoints for sensor metadata and readings, including refresh history functionality. Introduced sensor metadata configuration for various sensor types.
2026-09-04 Add generic sensor dashboard functionality
    Implement a generic sensor dashboard with functionalities to update latitude and longitude, initiate software updates, reboot, and shutdown. Includes dynamic sensor data visualization using Plotly.
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2026-09-05 Handle CO2 sensor display name
    Add special case for displaying CO2 sensor name.
2026-09-05 Implement timeout for CO2 sensor reading
    Added timeout handling for CO2 sensor readings to prevent indefinite blocking.
    [class_sensor_module.py]
2026-09-05 Improve weather readings collection in sensor module
    Refactor weather data collection logic and remove unused variables.
2026-09-06 Refactor sensor data handling and measurement insertion
    Refactor sensor data handling to use dynamic source sensors based on available readings. Update measurement insertion logic for humidity, pressure, and temperature.
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2026-09-06 Refactor SENSOR_SOURCE_MAP and ATTR_TO_READING initialization
    Moved SENSOR_SOURCE_MAP and ATTR_TO_READING to __init__ method.
2026-09-06 Refactor source_sensor assignment logic
    Updated source_sensor assignment to use device_readings for humidity, pressure, and temperature measurements.
2026-09-06 Sort metadata array to prioritize CO2 sensors
    Added sorting functionality to prioritize CO2 sensors in the metadata array.
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2026-09-07 Return sensor readings with location data
    Modified v2_sensor_readings to return sensor readings along with geographical location data (latitude and longitude).
2026-09-07 Refactor updateSensorReadings to handle sensor data
    Refactor updateSensorReadings function to directly process sensor data and update latitude and longitude.
2026-09-08 Add debug statements for rain rate handling
    Added debug print statements for rain rate insertion and setting.
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2026-09-08 Add debug logging for rain_rate and clean up code
    Added debug print statement for rain_rate insertion and removed commented-out code for CO2, pressure, humidity, and temperature.
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2026-09-08 Fix debug print statement for rain_rate insertion
    [class_sensor_module.py]
2026-09-08 Enhance debug logging for rain rate measurements
    Added debug print statements for device_readings keys and rain_rate checks.
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2026-09-08 Adjust sensor metadata for humidity and CO2
    Updated humidity and CO2 sensor metadata ranges.
2026-09-15 Implement MQTT client for Vantage weather data
    Added MQTT client functionality to receive weather data from Vantage. Updated sensor reading logic to prioritize MQTT readings over BME280 values.
2026-09-15 Implement logging for sensor data insertion
    Add logging for sensor measurements with latitude and longitude.
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2026-09-15 Optimize sensor initialization in periodic task
    Removed redundant instantiation of SensorModule inside the loop.
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2026-09-15 Remove PyIndi import and logging
    Removed PyIndi import and related logging for missing module.
    [class_sensor_module.py]
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2026-09-16 Refactor night shape building and shading logic
    Refactor buildNightShapes function to improve logic for determining night periods and update applyNightShading to use union of sensor data.
2026-09-16 Integrate global CO₂ history into dashboard charts
    Added global CO₂ history tracking and integrated it into existing charts. Updated layout to accommodate CO₂ data alongside other sensor data.
2026-09-16 Modify history chart creation for CO₂ sensor
    Skip creating a standalone CO₂ history chart and include it in other charts. Updated legend properties for better visibility.
2026-09-17 Add sudoers rule for SensorModule user
    Added a sudoers rule for the SensorModule user to restart indi2mqtt without a password. The rule is idempotent and checks for existing installations before proceeding.
2026-09-17 Fix indentation for error logging in sensor module
    [class_sensor_module.py]
2026-09-17 Swap order of traces in Plotly newPlot call
2026-09-17 Swap order of traces in Plotly newPlot function
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2026-09-17 Add marker color to CO₂ line in dashboard
    Added marker color to CO₂ line in dashboard chart.
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2026-09-17 Swap CO2 and sensor data order in Plotly updates
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2026-09-17 Remove CO₂ Y range calculation from dashboard.js
    Removed CO₂ range computation and related logic from the dashboard.
2026-09-17 Change CO₂ graph colors and update plot order - REVERT
2026-09-17 Refactor CO₂ trace line properties in dashboard.js - REVERT
2026-09-17 Refactor CO₂ trace and update plot order - REVERT to CO2 black
2026-09-17 Disable fill properties in scatter trace
    Comment out fill and fillcolor properties in scatter trace.
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2026-09-17 Implement currentShapes function for shape computation
    Added currentShapes function to compute night/day shapes based on current data window and sensor readings.
2026-09-18 Refactor CO₂ references to XCO₂ in dashboard.js
    Updated references from 'co2' to 'xco2' in history chart logic and commented out related checks.
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2026-09-18 Fix CO₂ label and improve y2 axis handling
    Updated CO₂ label and adjusted y2 axis configuration for non-CO₂ charts.
2026-09-18 Change CO2 min value from 300 to 200
    Updated CO2 sensor metadata minimum value.
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2026-09-18 Enhance CO₂ chart updates and overlay logic
    Update CO₂ chart with pre-industrial reference line and adjust overlay logic for other sensors.
2026-09-18 Expose sensors object as a global variable
    Added a debug hook to expose the sensors object globally.
2026-09-20 Refactor button and chart styles in CSS
    Removed padding and adjusted margin and gap in styles.
2026-09-26 Replace CO2 sensor screenshot in README
    Updated screenshot in README.md to reflect new image.
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2026-09-27 Fix SGP41 import path and enhance error logging
    Updated import statement for SGP41 and improved error handling.
    [class_sensor_module.py]
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2026-10-06 Fix capitalization in README description
    Correct capitalization of sensor names for consistency.
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2026-10-10 Add condition to skip chart creation for rain_today
    Prevent chart creation for 'rain_today' sensor.
2026-10-10 Exclude 'rain_today' from gauge updates
    Skip updating gauge for 'rain_today' sensor.
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2026-10-10 Fix syntax error in old method definition
    [class_database_mgt.py]
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
